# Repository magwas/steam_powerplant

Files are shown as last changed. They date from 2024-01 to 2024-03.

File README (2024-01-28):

An Open Hardware RISC-V based rugged, watercooled laptop with steampunk design.

Design Goals:

- based on the HiFive Unmatched Rev B board, because it is RISC-V
- actually useable
- waterproof
- shock proof
- long battery life
- water cooled
- steampunk

Not Design Goals:

- small
- lightweight

I wanted a RISC-V laptop. 
I usually carry my laptop in my car, and sometimes things happen to it.
So I choose ruggedness over lightness.
The laptop is my single most important object, so I looked up the parts I need, without regard to their price.
Well, later I added up the prices, and got a little shock.
But I have already ordered everything, so...

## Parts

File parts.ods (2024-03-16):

what | type | price (HUF) | dimensions | remark | delivery | url
summary |  | 926262.84
motherboard | hifive unmatched rev b | 273,475 | 170x170x40 | deadend | delivered | https://hu.mouser.com/ProductDetail/SiFive/HF105-001?qs=Imq1NPwxi75JBw6ulD0quQ%3D%3D
monitor+touch | ZSUS 15.6 inch | 40,581 | 345x194x10 |  | delivered | https://www.aliexpress.com/item/1005006082064188.html
kbd | K-TEK-B312-OTB-KP-FN-BL-DWP | 126,000 | 330x123x(33.5+13) | deadend | delivered | https://www.key-tek.cn/Productview.asp?id=1040
ssd | Kingspec XG 7000 | 23,776 |  | 1 TB NVME | https://www.microstore.hu/index.php?route=account/order | https://www.newegg.com/KingSpec-1TB-XG-7000-Series/p/0D9-000D-00171?Item=9SIB1V8JVN3873
wifi | a régi gépből |  |  |  | delivered
accumulators | Sony VTC6 18650 3000 mAh | 140,400 | 18*65 | 4*4 db 14.4V |  | https://www.intercell.hu/sony_vtc6_18650_37v_3000mah_us18650vtc6_li-ion_ipari_cella_akkuakkumulator_30538
BMS | 4S 40A BMS | 34,650 | 63.5x43.18x7.2 |  |  | https://www.amazon.com/Enhanced-Lithium-Protection-Charging-Motorcycle/dp/B08NJTS9DV
mic | CMC-6035T-C1 | 1,865 | 2 pieces |  | https://hu.mouser.com/account/orders/detail | https://hu.mouser.com/ProductDetail/179-CMC-6035T-C1
speaker | ASE05008MS-LWC60 | 8550 | 4 pieces |  | https://hu.mouser.com/account/orders/detail | https://hu.mouser.com/ProductDetail/665-ASE05008MS-LWC60
camera | arducam | 12,200 | 38x38 | deadend | delivered | https://www.amazon.com/Arducam-Computer-Automatic-Switching-All-Day/dp/B0829HZ3Q7?rnid=59788738011&s=pc
camera | SEN0286 | 18,135 | two pieces |  | https://hu.mouser.com/account/orders/detail?qs=9C%2fvjDbyW3XbZVweW%2fGf%2f3c3bGPWTQrU4GrpttTNG8U%3d | https://hu.mouser.com/ProductDetail/426-SEN0286
pump |  |  |  |  |  | https://www.newegg.com/p/37B-0003-00087?Item=9SIAEKSAUY1026
box | sárgaréz lemez 0.7 | 48,768 | 1x300x2000 |  | delivered | https://vasaruhaz.hu/sargarez-vorosrez-bronz/sargarez-lemezek/sargarez-lemez-cu-zn-37-fk0710002000-2209
pcie riser 90 degrees |  | 3500 | 116x41x13 |  | delivered | https://www.amazon.com/GODSHARK-PCI-Express-Riser-Degree-Adapter/dp/B07VV18PQD
video card | amd radeon R7 240 | 10385 | 146x70x2.5 |  | delivered | https://www.amazon.com/PowerColor-Radeon-240-64-bit-Graphics/dp/B09YHVRYNH?rnid=386442011&s=pc
Usb 3.0 hub |  | 3000 |  |  |  | https://www.amazon.com/Extender-Splitter-MacBook-Chromebook-Pixelbook/dp/B09MLRPTT2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
battery springs | 1,5x10/18x13, 1+3+1 | 10100 |  | 1.5*5 mm laposan |  | https://rugobolt.hu/Kupos-nyomorugo-15x10/18x13-mm-menetszam-1-3-1-nat
copper braid | 9.5x7.6m | 10251 |  | 7.6m |  | https://www.techflex.de/flexo-copper-copper-braid-for-grounding-and-shielding.html
silicone tube | 7x10 szilikon cső | 2655 | Din=7 Dout=10 | 5m | delivered | https://szilikon-webaruhaz.hu/id/00024-7x10-mm-es-szilikon-cso
copper tube cső | 20x1x4000 | 16720 |  | 4m | no | https://vasaruhaz.hu/sargarez-vorosrez-bronz/sargarez-cso/sargarez-cso-cuzn-37-fk2014000-2274
filter coil | Rtoroid=2 N=77 Rcoil=0.5 Dwire=2 | 0 | D=10 réz rúdból a tórusz | 4.7 uH |  | http://hyperphysics.phy-astr.gsu.edu/hbase/magnetic/indtor.html
bronze rod | D=10 |  |  |  | no
LM2576T-12 | 4db | 8452 | 5-TO220 | deadend | delivered | https://hu.mouser.com/ProductDetail/926-LM2596T-12-LF03
capacitor | 1000 uF 50V 4db | 279.8 | 12.5x20 | deadend | delivered
capacitor | 100uF 4db | 91.28 | 8x12 | deadend | delivered
diode | 1N5822 4db | 158.76 | 5.6x9.5 | deadend | delivered
fuse | BD280-1130-20/16 |  |  |  | delivered | https://hu.mouser.com/ProductDetail/Littelfuse/BD280-1130-20-16?qs=bZ3KlHYEm0Y61%252BMNFrrJgA%3D%3D
copper wire | 1 punds, 12 awg d=12mm | 17521 |  |  | delivered | https://www.amazon.com/Electric-Copper-Enameled-Industrial-Transmission/dp/B0BN6Y6PN4
usb connector | musb-A511-N1 * 4 |  |  |  | delivered | https://hu.mouser.com/datasheet/2/18/1/AMPH_S_A0003149851_1-2536612.pdf
rj45 | mrjr5c80M1 |  |  |  | delivered | https://cdn.amphenol-cs.com/media/wysiwyg/files/drawing/p-mrjr-5cxx-xc.pdf
on/off switch |  |  |  | deadend | delivered | https://hu.mouser.com/ProductDetail/Carling-Technologies/V8BAAV0B-A9C00-000?qs=W0yvOO0ixfG9jnUCBtfRnQ%3D%3D
on/off switch | TMS3T5B2M6RE | 9945 | 5 pieces |  | https://hu.mouser.com/account/orders/detail?qs=9C%2fvjDbyW3XbZVweW%2fGf%2f3c3bGPWTQrU4GrpttTNG8U%3d | https://hu.mouser.com/ProductDetail/506-TMS3T5B2M6RE
glass plate for my 3d printer |  | 6800 |  |  | https://www.szamlazz.hu/szamla/fiok/wc2u6sn7r4264vhrz755tqzbhm9tj23dq7re?szfejguid=f8qyks3z6pzmtfh7te5a56ia
alu plate |  | 17100 | 1x1000x2000 |  | delivered
wood | zebrano | 11000 |  |  | delivered
ATX from 12V | picopsu | 34000 |  |  |  | https://mitxpc.com/products/pspsu150ac120
M4x5 screw | 200 pieces | 5411 |  |  | https://www.mcmaster.com/order-history/order/65d309e477a2e629e022db77/ | https://www.mcmaster.com/catalog/130/3478/97595A276
M4 nut | 200 pieces | 3608 |  |  | https://www.mcmaster.com/order-history/order/65d309e477a2e629e022db77/ | https://www.mcmaster.com/catalog/130/3635/90690A030
pointing stick |  | 26885 |  | ordered |  | https://www.sprintek.com/en/products/pointing_stick/SK8707-06.aspx

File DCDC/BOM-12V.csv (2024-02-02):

Part | Manufacturer | Part Number | Quantity | Price ($) | Footprint (mm²) | Description
Ccomp3-3 | MuRata | GRM1555C1H911JA01D | 1 | 0.02 | 3 | Cap: 910 pF Total Derated Cap: 910 pF VDC: 50 V ESR: 1 mΩ Package: 0402
Cilim-3 | MuRata | GRM1885C2A100JA01D | 1 | 0.02 | 4.68 | Cap: 10 pF Total Derated Cap: 10 pF VDC: 100 V ESR: 1 mΩ Package: 0603
Css-3 | MuRata | GRM155R71C563KA88D | 1 | 0.01 | 3 | Cap: 56 nF Total Derated Cap: 56 nF VDC: 16 V ESR: 1 mΩ Package: 0402
Cin-3 | MuRata | GRM32ER71H475KA88L | 1 | 0.16 | 14.7 | Cap: 4.7 µF Total Derated Cap: 3.3 µF VDC: 50 V ESR: 1 mΩ Package: 1210
Ruv1-3 | Yageo | RC0201FR-7D68K1L | 1 | 0.01 | 2.08 | Resistance: 68.1 kΩ Tolerance: 1.0% Power: 50 mW
Ccomp2-3 | MuRata | GRM155R71H122KA01D | 1 | 0.01 | 3 | Cap: 1.2 nF Total Derated Cap: 1.2 nF VDC: 50 V ESR: 1 mΩ Package: 0402
Ccomp1-3 | MuRata | GRM155R71C153KA01D | 1 | 0.01 | 3 | Cap: 15 nF Total Derated Cap: 15 nF VDC: 16 V ESR: 1 mΩ Package: 0402
Rt-3 | Vishay-Dale | CRCW040269K8FKED | 1 | 0.01 | 3 | Resistance: 69.8 kΩ Tolerance: 1.0% Power: 63 mW
M1-3 | Texas Instruments | CSD17581Q3A | 1 | 0.18 | 18.49 | VdsMax: 30 V IdsMax: 60 Amps
Rfbb-3 | Vishay-Dale | CRCW04021K27FKED | 1 | 0.01 | 3 | Resistance: 1.27 kΩ Tolerance: 1.0% Power: 63 mW
Rcomp2-3 | Vishay-Dale | CRCW04021K82FKED | 1 | 0.01 | 3 | Resistance: 1.82 kΩ Tolerance: 1.0% Power: 63 mW
Cbst-3 | MuRata | GRM188R61E104KA01D | 1 | 0.01 | 4.68 | Cap: 100 nF Total Derated Cap: 67 nF VDC: 25 V ESR: 30 mΩ Package: 0603
Rfbt-3 | Yageo | RC0603FR-0718KL | 1 | 0.01 | 4.68 | Resistance: 18 kΩ Tolerance: 1.0% Power: 100 mW
Rvin-3 | Vishay-Dale | CRCW06032R10FKEA | 1 | 0.01 | 4.68 | Resistance: 2.1 Ω Tolerance: 1.0% Power: 100 mW
Cvin-3 | TDK | CGA3E2X7R1H104K080AA | 1 | 0.01 | 4.68 | Cap: 100 nF Total Derated Cap: 82 nF VDC: 50 V ESR: 29.6 mΩ Package: 0603
Rpgood-3 | Yageo | RC0603FR-0720KL | 1 | 0.01 | 4.68 | Resistance: 20 kΩ Tolerance: 1.0% Power: 100 mW
U1-3 | Texas Instruments | LM5145RGYR | 1 | 1.318 | 24.75
Cvcc-3 | TDK | C1005X5R1V225K050BC | 1 | 0.06 | 3 | Cap: 2.2 µF Total Derated Cap: 93 nF VDC: 35 V ESR: 1 mΩ Package: 0402
M2-3 | Texas Instruments | CSD17577Q3A | 1 | 0.15 | 18.49 | VdsMax: 30 V IdsMax: 35 Amps
L1-3 | Coilcraft | XAL1010-472MEB | 1 | 1.71 | 159.6 | L: 4.7 µH DCR: 5.2 mΩ IDC: 24 A
Cout-3 | Panasonic | 20SVPF56MX | 1 | 0.47 | 53.29 | Cap: 56 µF Total Derated Cap: 56 µF VDC: 20 V ESR: 30 mΩ Package: 5x5.9
Ruv2-3 | Yageo | RC0603FR-079K1L | 1 | 0.01 | 4.68 | Resistance: 9.1 kΩ Tolerance: 1.0% Power: 100 mW
Rilim-3 | Vishay-Dale | CRCW0402619RFKED | 1 | 0.01 | 3 | Resistance: 619 Ω Tolerance: 1.0% Power: 63 mW
Rcomp1-3 | Vishay-Dale | CRCW04021K78FKED | 1 | 0.01 | 3 | Resistance: 1.78 kΩ Tolerance: 1.0% Power: 63 mW
Rvcc-3 | Yageo | RC0603FR-0720KL | 1 | 0.01 | 4.68 | Resistance: 20 kΩ Tolerance: 1.0% Power: 100 mW

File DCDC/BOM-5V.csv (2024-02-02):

Part | Manufacturer | Part Number | Quantity | Price ($) | Footprint (mm²) | Description
Ccomp3-1 | TDK | CGA2B2X7R1H471K050BA | 1 | 0.01 | 3 | Cap: 470 pF Total Derated Cap: 470 pF VDC: 50 V ESR: 4.96 Ω Package: 0402
Cilim-1 | MuRata | GQM2195C2A5R1CB01D | 1 | 0.15 | 6.75 | Cap: 5.1 pF Total Derated Cap: 5.1 pF VDC: 100 V ESR: 1 mΩ Package: 0805
Css-1 | MuRata | GRM155R71C563KA88D | 1 | 0.01 | 3 | Cap: 56 nF Total Derated Cap: 56 nF VDC: 16 V ESR: 1 mΩ Package: 0402
Cin-1 | MuRata | GRM32ER71H475KA88L | 1 | 0.16 | 14.7 | Cap: 4.7 µF Total Derated Cap: 3.3 µF VDC: 50 V ESR: 1 mΩ Package: 1210
Ruv1-1 | Yageo | RC0201FR-7D68K1L | 1 | 0.01 | 2.08 | Resistance: 68.1 kΩ Tolerance: 1.0% Power: 50 mW
Ccomp2-1 | MuRata | GRM155R71H821KA01D | 1 | 0.01 | 3 | Cap: 820 pF Total Derated Cap: 820 pF VDC: 50 V ESR: 1 mΩ Package: 0402
Ccomp1-1 | MuRata | GRM155R71C822KA01D | 1 | 0.01 | 3 | Cap: 8.2 nF Total Derated Cap: 8.2 nF VDC: 16 V ESR: 1 mΩ Package: 0402
Rt-1 | Vishay-Dale | CRCW040239K2FKED | 1 | 0.01 | 3 | Resistance: 39.2 kΩ Tolerance: 1.0% Power: 63 mW
M1-1 | Texas Instruments | CSD17579Q3A | 1 | 0.12 | 18.49 | VdsMax: 30 V IdsMax: 20 Amps
Rfbb-1 | Vishay-Dale | CRCW04023K40FKED | 1 | 0.01 | 3 | Resistance: 3.4 kΩ Tolerance: 1.0% Power: 63 mW
Rcomp2-1 | Vishay-Dale | CRCW0402162RFKED | 1 | 0.01 | 3 | Resistance: 162 Ω Tolerance: 1.0% Power: 63 mW
Cbst-1 | MuRata | GRM188R61E104KA01D | 1 | 0.01 | 4.68 | Cap: 100 nF Total Derated Cap: 67 nF VDC: 25 V ESR: 30 mΩ Package: 0603
Rfbt-1 | Yageo | RC0603FR-0718KL | 1 | 0.01 | 4.68 | Resistance: 18 kΩ Tolerance: 1.0% Power: 100 mW
Rvin-1 | Vishay-Dale | CRCW06032R10FKEA | 1 | 0.01 | 4.68 | Resistance: 2.1 Ω Tolerance: 1.0% Power: 100 mW
Cvin-1 | TDK | CGA3E2X7R1H104K080AA | 1 | 0.01 | 4.68 | Cap: 100 nF Total Derated Cap: 82 nF VDC: 50 V ESR: 29.6 mΩ Package: 0603
Rpgood-1 | Yageo | RC0603FR-0720KL | 1 | 0.01 | 4.68 | Resistance: 20 kΩ Tolerance: 1.0% Power: 100 mW
U1-1 | Texas Instruments | LM5145RGYR | 1 | 1.318 | 24.75
Cvcc-1 | TDK | C1005X5R1V225K050BC | 1 | 0.06 | 3 | Cap: 2.2 µF Total Derated Cap: 93 nF VDC: 35 V ESR: 1 mΩ Package: 0402
M2-1 | Texas Instruments | CSD17577Q3A | 1 | 0.15 | 18.49 | VdsMax: 30 V IdsMax: 35 Amps
L1-1 | Coilcraft | XAL1010-332MEB | 1 | 1.71 | 159.6 | L: 3.3 µH DCR: 3.7 mΩ IDC: 25 A
Cout-1 | Kemet | C1210C106K8PACTU | 2 | 0.22 | 14.7 | Cap: 10 µF Total Derated Cap: 19 µF VDC: 10 V ESR: 8 mΩ Package: 1210
Ruv2-1 | Yageo | RC0603FR-079K1L | 1 | 0.01 | 4.68 | Resistance: 9.1 kΩ Tolerance: 1.0% Power: 100 mW
Rilim-1 | Vishay-Dale | CRCW04021K74FKED | 1 | 0.01 | 3 | Resistance: 1.74 kΩ Tolerance: 1.0% Power: 63 mW
Rcomp1-1 | Vishay-Dale | CRCW04021K54FKED | 1 | 0.01 | 3 | Resistance: 1.54 kΩ Tolerance: 1.0% Power: 63 mW
Rvcc-1 | Yageo | RC0603FR-0720KL | 1 | 0.01 | 4.68 | Resistance: 20 kΩ Tolerance: 1.0% Power: 100 mW

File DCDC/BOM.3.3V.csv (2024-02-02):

Part | Manufacturer | Part Number | Quantity | Price ($) | Footprint (mm²) | Description
Ccomp3-2 | TDK | CGA2B2X7R1H331K050BA | 1 | 0.01 | 3 | Cap: 330 pF Total Derated Cap: 330 pF VDC: 50 V ESR: 6.53 Ω Package: 0402
Cilim-2 | MuRata | GQM2195C2A5R1CB01D | 1 | 0.15 | 6.75 | Cap: 5.1 pF Total Derated Cap: 5.1 pF VDC: 100 V ESR: 1 mΩ Package: 0805
Css-2 | MuRata | GRM155R71C563KA88D | 1 | 0.01 | 3 | Cap: 56 nF Total Derated Cap: 56 nF VDC: 16 V ESR: 1 mΩ Package: 0402
Cin-2 | MuRata | GRM32ER71H475KA88L | 1 | 0.16 | 14.7 | Cap: 4.7 µF Total Derated Cap: 3.3 µF VDC: 50 V ESR: 1 mΩ Package: 1210
Ruv1-2 | Yageo | RC0201FR-7D68K1L | 1 | 0.01 | 2.08 | Resistance: 68.1 kΩ Tolerance: 1.0% Power: 50 mW
Ccomp2-2 | MuRata | GRM155R71C102KA01D | 1 | 0.01 | 3 | Cap: 1 nF Total Derated Cap: 1 nF VDC: 16 V ESR: 1 mΩ Package: 0402
Ccomp1-2 | MuRata | GRM155R71C822KA01D | 1 | 0.01 | 3 | Cap: 8.2 nF Total Derated Cap: 8.2 nF VDC: 16 V ESR: 1 mΩ Package: 0402
Rt-2 | Vishay-Dale | CRCW040239K2FKED | 1 | 0.01 | 3 | Resistance: 39.2 kΩ Tolerance: 1.0% Power: 63 mW
M1-2 | Texas Instruments | CSD17579Q3A | 1 | 0.12 | 18.49 | VdsMax: 30 V IdsMax: 20 Amps
Rfbb-2 | Vishay-Dale | CRCW04025K76FKED | 1 | 0.01 | 3 | Resistance: 5.76 kΩ Tolerance: 1.0% Power: 63 mW
Rcomp2-2 | Vishay-Dale | CRCW0402237RFKED | 1 | 0.01 | 3 | Resistance: 237 Ω Tolerance: 1.0% Power: 63 mW
Cbst-2 | MuRata | GRM188R61E104KA01D | 1 | 0.01 | 4.68 | Cap: 100 nF Total Derated Cap: 67 nF VDC: 25 V ESR: 30 mΩ Package: 0603
Rfbt-2 | Yageo | RC0603FR-0718KL | 1 | 0.01 | 4.68 | Resistance: 18 kΩ Tolerance: 1.0% Power: 100 mW
Rvin-2 | Vishay-Dale | CRCW06032R10FKEA | 1 | 0.01 | 4.68 | Resistance: 2.1 Ω Tolerance: 1.0% Power: 100 mW
Cvin-2 | TDK | CGA3E2X7R1H104K080AA | 1 | 0.01 | 4.68 | Cap: 100 nF Total Derated Cap: 82 nF VDC: 50 V ESR: 29.6 mΩ Package: 0603
Rpgood-2 | Yageo | RC0603FR-0720KL | 1 | 0.01 | 4.68 | Resistance: 20 kΩ Tolerance: 1.0% Power: 100 mW
U1-2 | Texas Instruments | LM5145RGYR | 1 | 1.318 | 24.75
Cvcc-2 | TDK | C1005X5R1V225K050BC | 1 | 0.06 | 3 | Cap: 2.2 µF Total Derated Cap: 93 nF VDC: 35 V ESR: 1 mΩ Package: 0402
M2-2 | Texas Instruments | CSD17577Q3A | 1 | 0.15 | 18.49 | VdsMax: 30 V IdsMax: 35 Amps
L1-2 | Bourns | SRP1270-2R2M | 1 | 0.83 | 246.49 | L: 2.2 µH DCR: 4.2 mΩ IDC: 22 A
Cout-2 | Kemet | C1210C106K8PACTU | 2 | 0.22 | 14.7 | Cap: 10 µF Total Derated Cap: 20 µF VDC: 10 V ESR: 8 mΩ Package: 1210
Ruv2-2 | Yageo | RC0603FR-079K1L | 1 | 0.01 | 4.68 | Resistance: 9.1 kΩ Tolerance: 1.0% Power: 100 mW
Rilim-2 | Vishay-Dale | CRCW04021K50FKED | 1 | 0.01 | 3 | Resistance: 1.5 kΩ Tolerance: 1.0% Power: 63 mW
Rcomp1-2 | Vishay-Dale | CRCW04021K27FKED | 1 | 0.01 | 3 | Resistance: 1.27 kΩ Tolerance: 1.0% Power: 63 mW
Rvcc-2 | Yageo | RC0603FR-0720KL | 1 | 0.01 | 4.68 | Resistance: 20 kΩ Tolerance: 1.0% Power: 100 mW

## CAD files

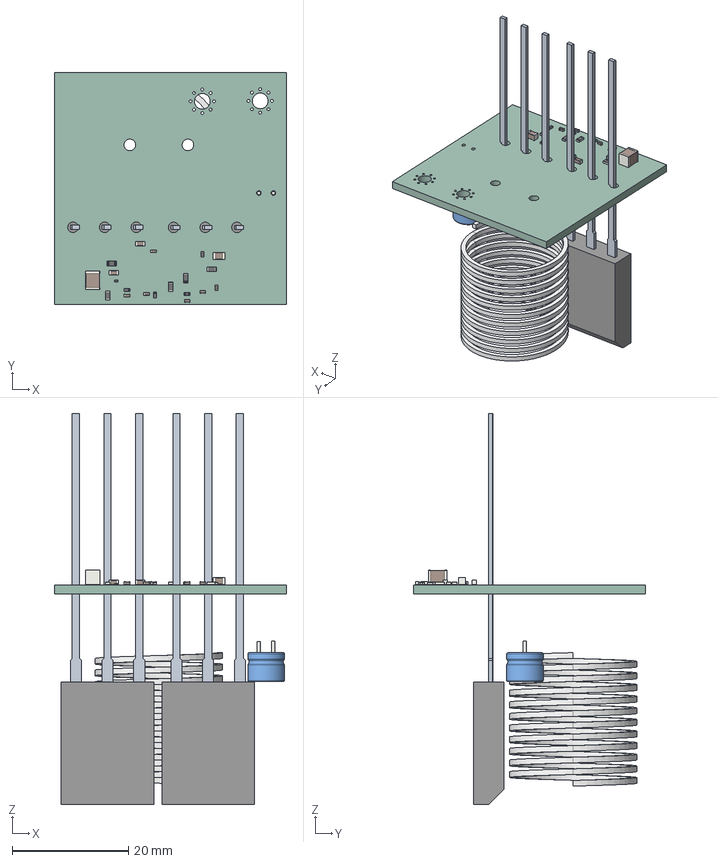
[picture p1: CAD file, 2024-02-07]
DCDC/dcdc3.step
40.0 x 40.0 x 67.3 mm
C_0805_2012Metric
R_0402_1005Metric x 5
R_0603_1608Metric x 5
C_0402_1005Metric x 5
C_1210_3225Metric
C_0603_1608Metric x 2
R_0201_0603Metric
C_Radial_D63mm_H50mm_P250mm
ASSEMBLY x 2
_autosave-dcdc3_PCB

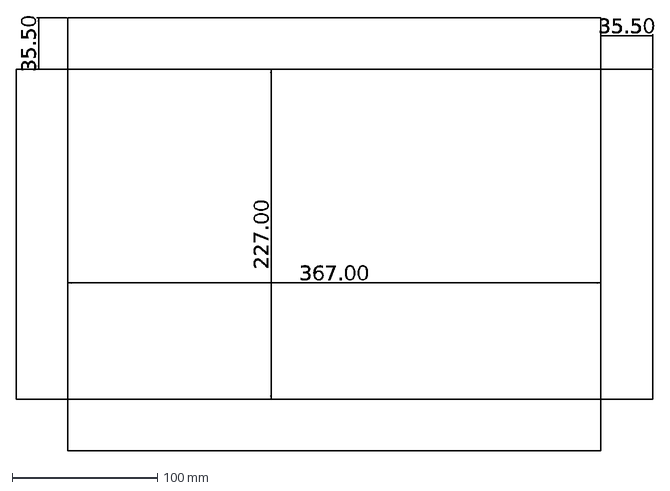
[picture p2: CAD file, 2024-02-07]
plans/bottom_box_origami.dxf
35.50
367.00
227.00

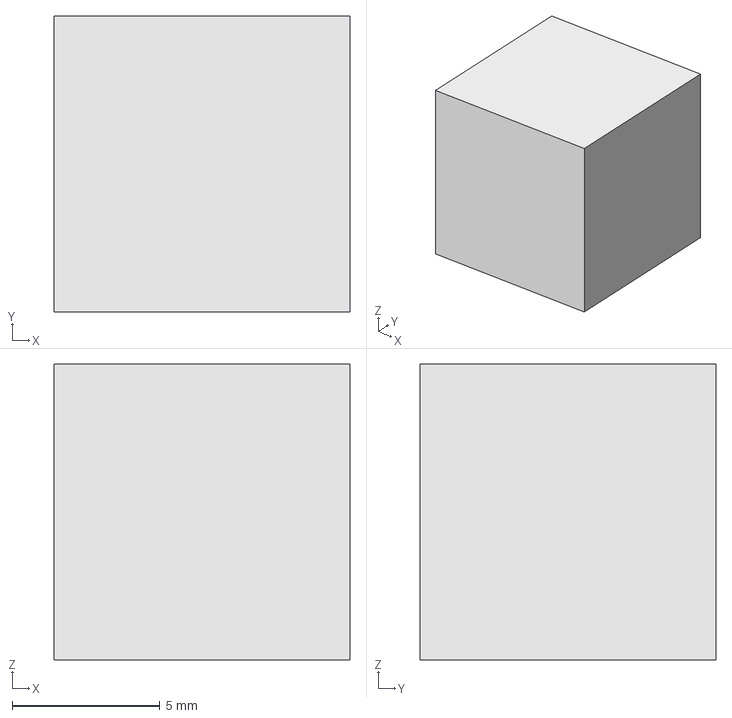
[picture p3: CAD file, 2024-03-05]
pump.FCStd
10.0 x 10.0 x 10.0 mm

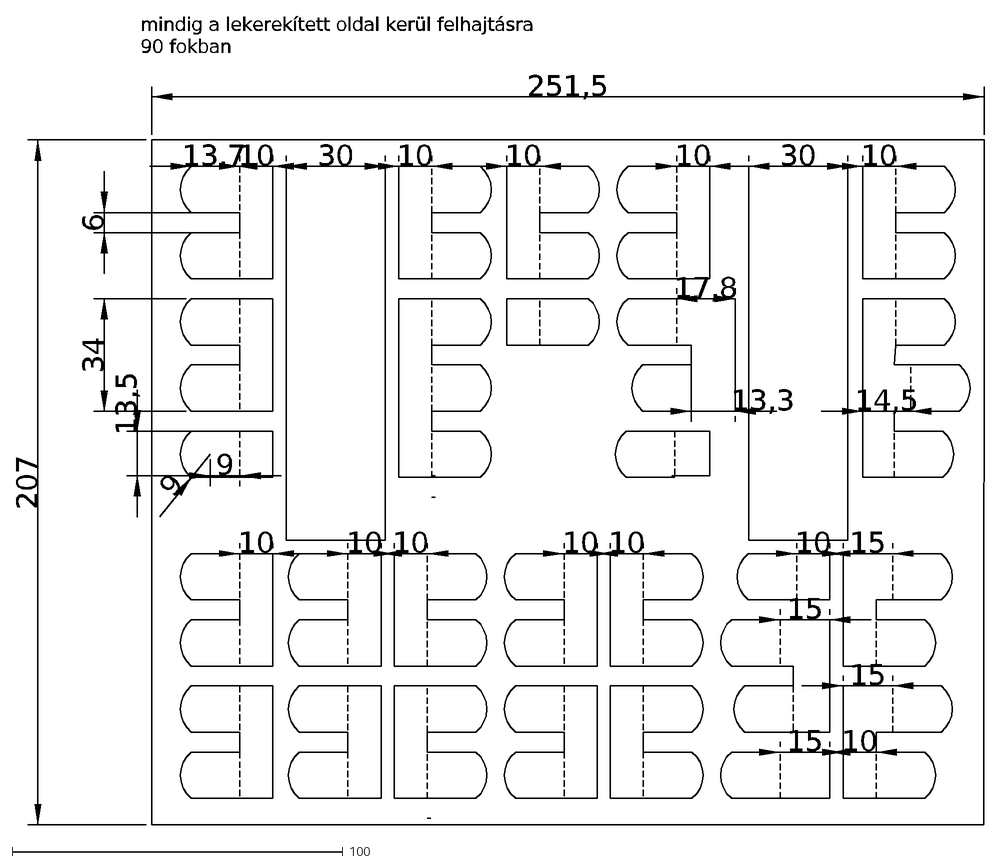
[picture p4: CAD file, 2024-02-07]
battery_contacts.dxf
9
10
13,7
13,5
17,8
13,3
30
14,5
6
15
34
207
251,5
mindig a lekerekített oldal kerül felhajtásra 90 fokban

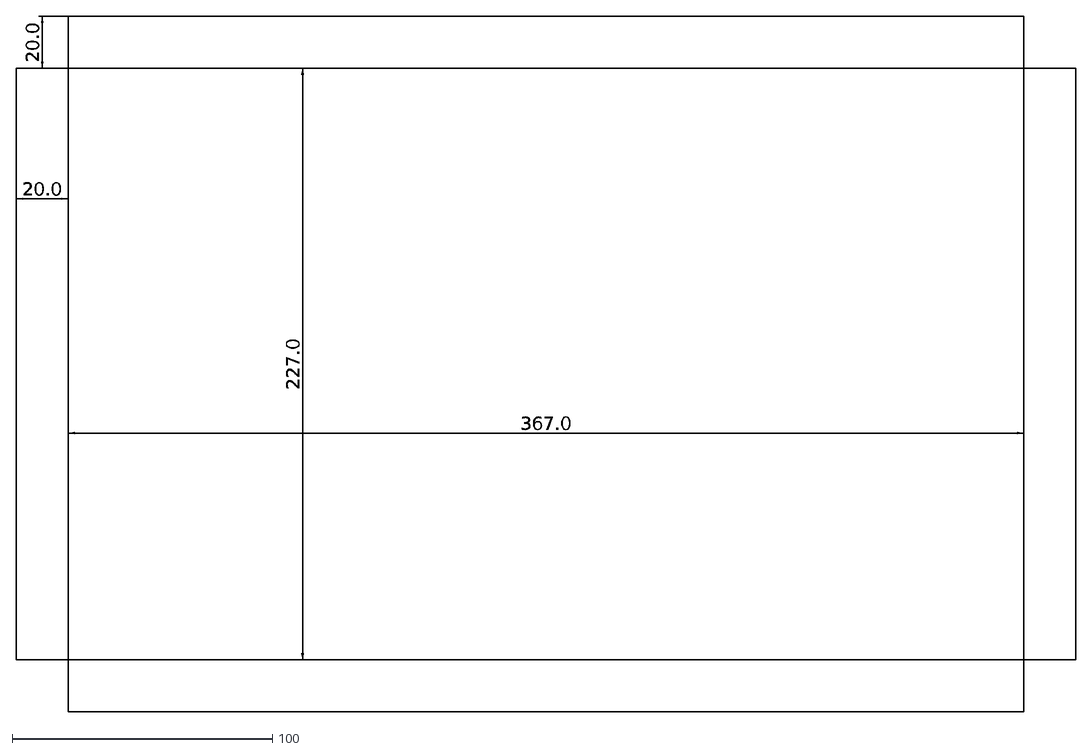
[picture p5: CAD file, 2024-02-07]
plans/top_box_origami.dxf
227.0
20.0
367.0

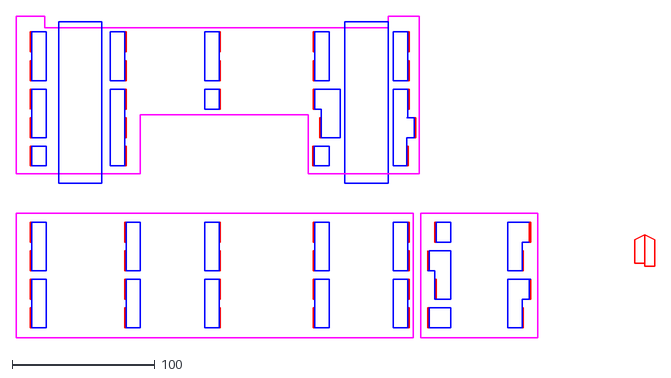
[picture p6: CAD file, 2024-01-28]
sketches.dxf
447.0 x 225.0

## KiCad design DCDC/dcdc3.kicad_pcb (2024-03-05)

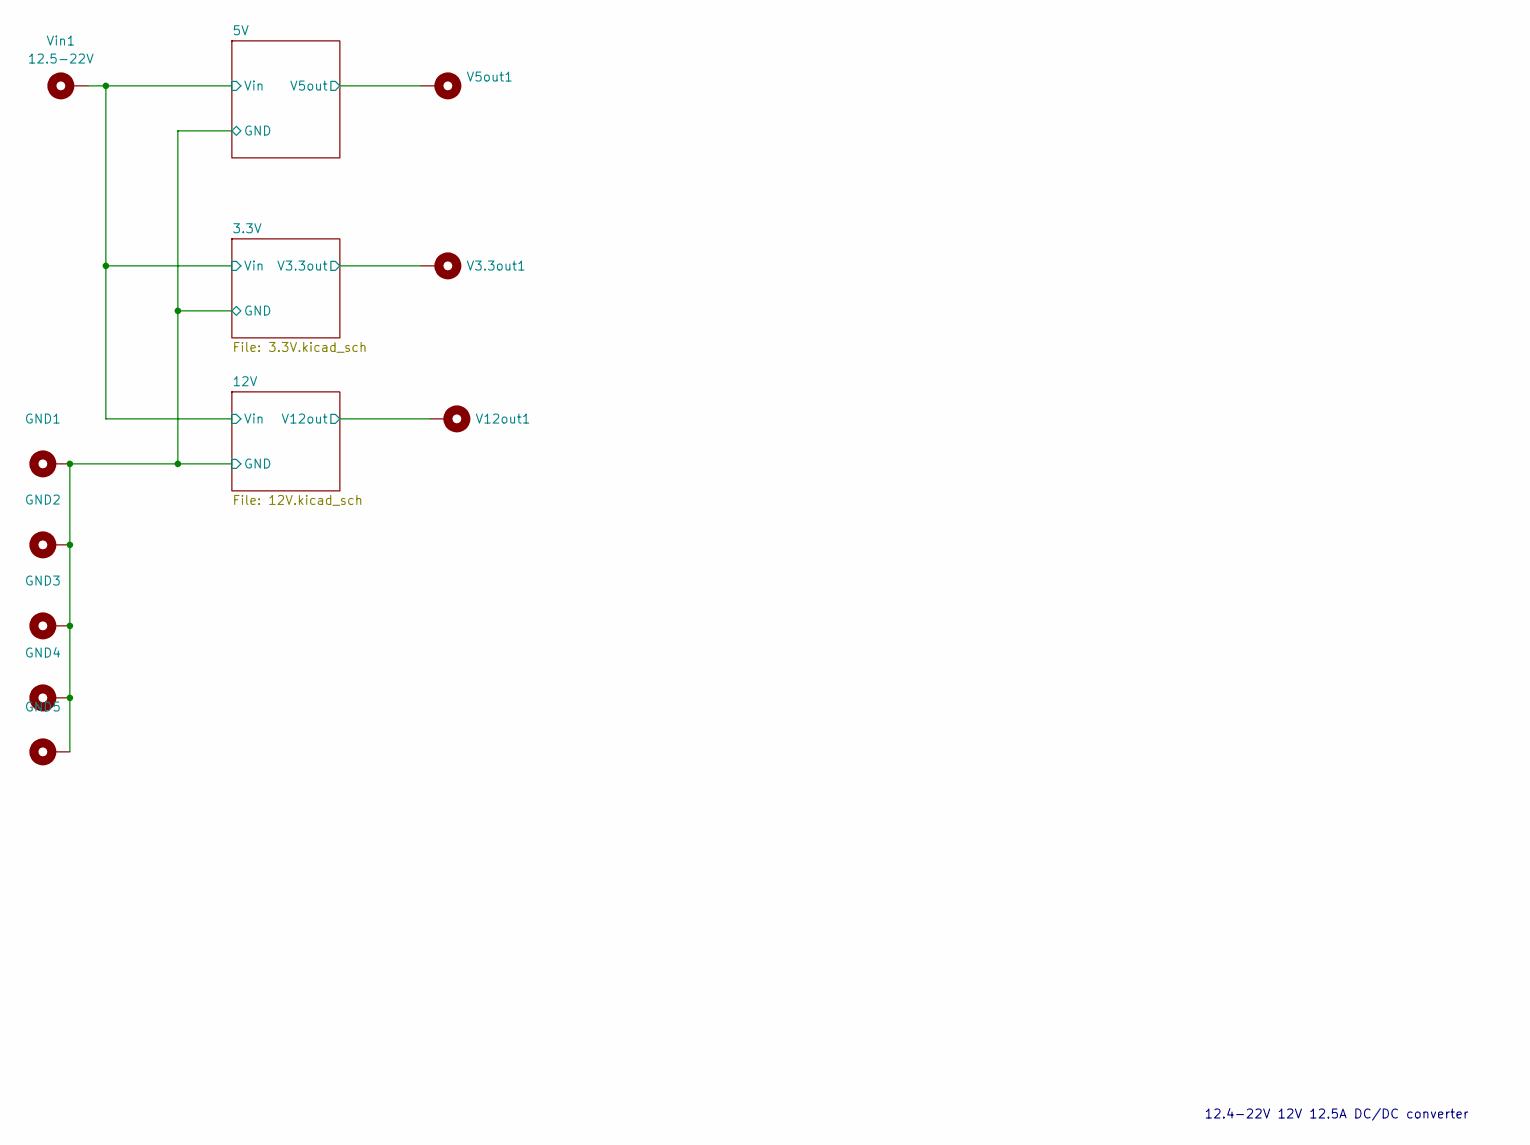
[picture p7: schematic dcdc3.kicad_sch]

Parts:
GND1, GND2, GND3, GND4, GND5: MountingHole_2.7mm_M2.5_Pad_Via
V3.3out1, V5out1, V12out1: MountingHole_2.7mm_M2.5_Pad_Via
Vin1: 12.5-22V; MountingHole_2.7mm_M2.5_Pad_Via

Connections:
/3.3V/V3.3out: V3.3out1.1; also elsewhere on the board
/5V/V5out: V5out1.1; also elsewhere on the board
/12V/GND: GND1.1, GND2.1, GND3.1, GND4.1, GND5.1; also elsewhere on the board
/12V/V12out: V12out1.1; also elsewhere on the board
/12V/Vin: Vin1.1; also elsewhere on the board

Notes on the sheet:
12.4-22V 12V 12.5A DC/DC converter

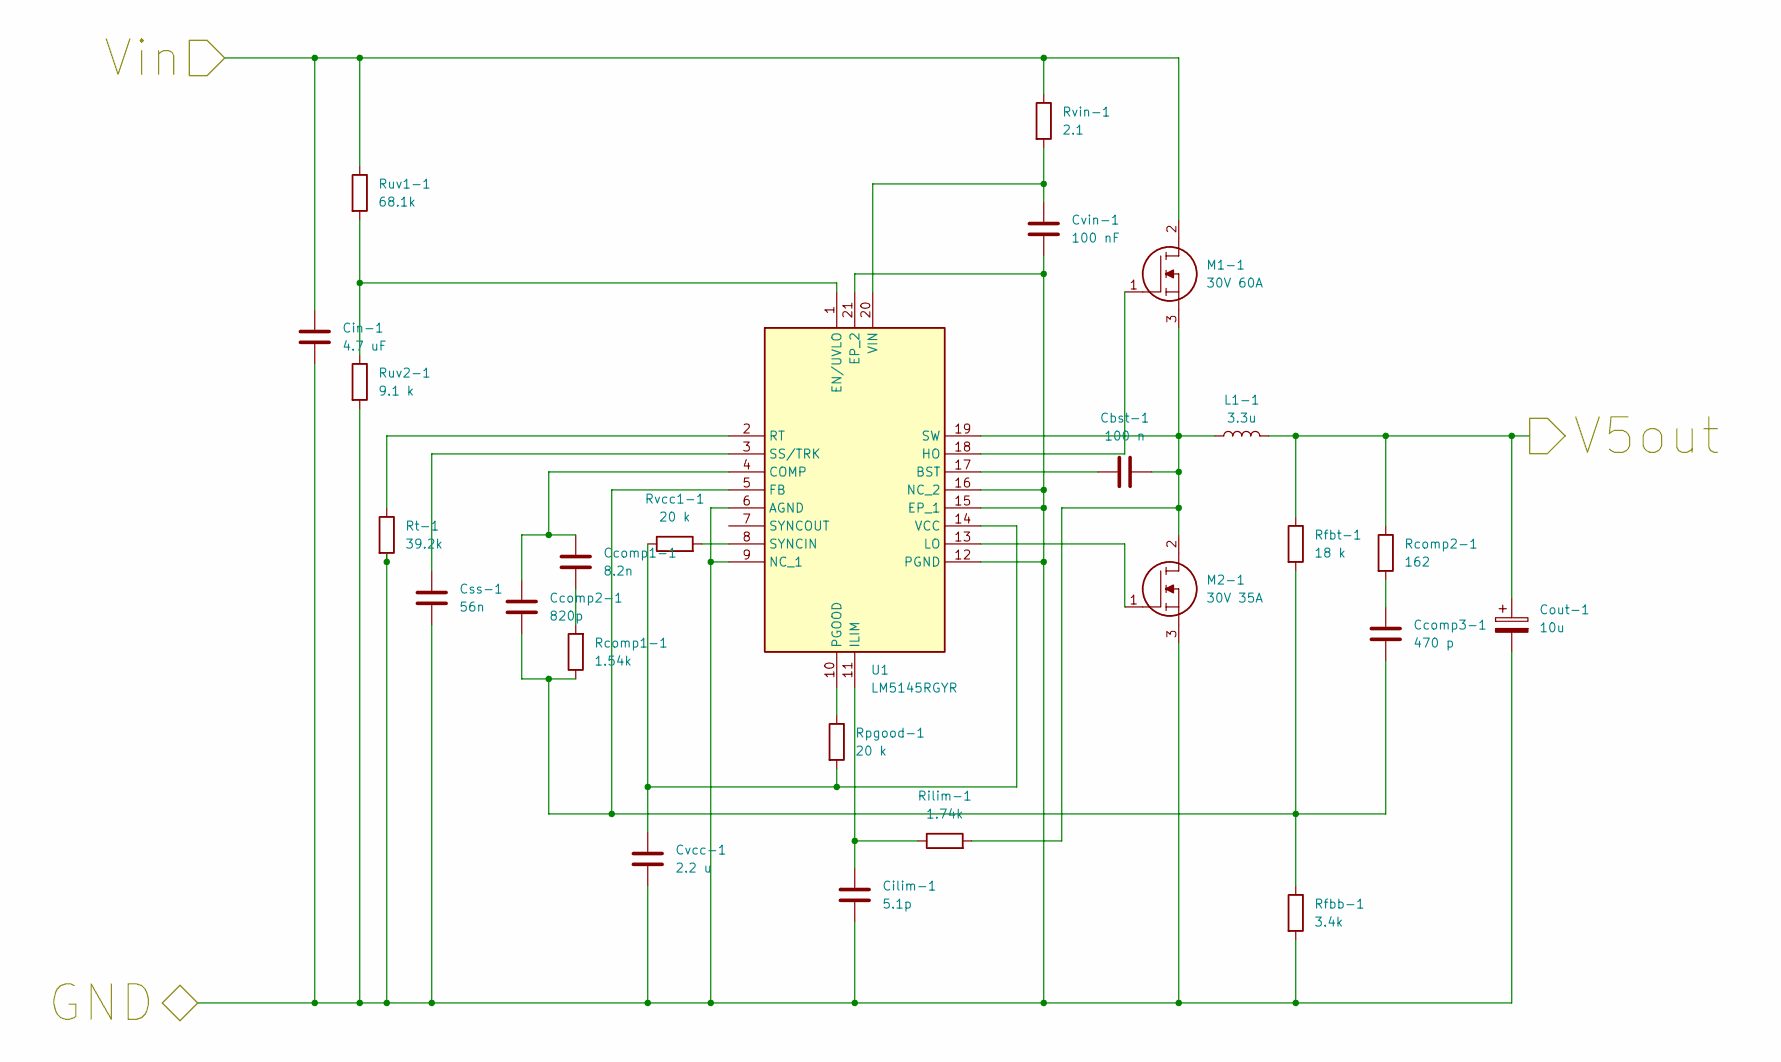
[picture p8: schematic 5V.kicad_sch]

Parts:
Cbst-1: 100 n; C_0603_1608Metric; Manufacturer_Part_Number C0603C104J1RACAUTO
Ccomp1-1: 8.2n; C_0402_1005Metric; Manufacturer_Part_Number GRM155R71C822KA01D
Ccomp2-1: 820p; C_0402_1005Metric; Manufacturer_Part_Number GRM155R71H821KA01D
Ccomp3-1: 470 p; C_0402_1005Metric; Manufacturer_Part_Number CGA2B2X7R1H471K050BA
Cilim-1: 5.1p; C_0805_2012Metric; Manufacturer_Part_Number C0805C519DBGACTU
Cin-1: 4.7 uF; C_1210_3225Metric; Manufacturer_Part_Number GRM32ER71H475KA88L
Cout-1: 10u; C_Radial_D10.0mm_H12.5mm_P5.00mm; Manufacturer_Part_Number KTD500B106M55A0T00
Css-1: 56n; C_0402_1005Metric; Manufacturer_Part_Number GRM155R71C563KA88D
Cvcc-1: 2.2 u; C_0402_1005Metric; Manufacturer_Part_Number C1005X5R1V225K050BC
Cvin-1: 100 nF; C_0603_1608Metric; Manufacturer_Part_Number CGA3E2X7R1H104K080AA
L1-1: 3.3u; A3mmCoil; Manufacturer_Part_Number D=15mm,N=15,L=15mm,d=2mm
M1-1: 30V 60A; TO545P521X1594X2566-3P; Mouser Part Number 747-IXFX360N10T
M2-1: 30V 35A; TO545P521X1594X2566-3P; Mouser Part Number 747-IXFX360N10T
Rcomp1-1: 1.54k; R_0402_1005Metric; Manufacturer_Part_Number CRCW04021K78FKED
Rcomp2-1: 162; R_0402_1005Metric; Manufacturer_Part_Number CRCW0402162RFKED
Rfbb-1: 3.4k; R_0402_1005Metric; Manufacturer_Part_Number CRCW04023K40FKED
Rfbt-1: 18 k; R_0603_1608Metric; Manufacturer_Part_Number RC0603FR-0718KL
Rilim-1: 1.74k; R_0402_1005Metric; Manufacturer_Part_Number CRCW04021K74FKED
Rpgood-1: 20 k; R_0603_1608Metric; Manufacturer_Part_Number RC0603FR-0720KL
Rt-1: 39.2k; R_0402_1005Metric; Manufacturer_Part_Number CRCW040239K2FKED
Ruv1-1: 68.1k; R_0603_1608Metric; Manufacturer_Part_Number ERA-3VEB6812V
Ruv2-1: 9.1 k; R_0603_1608Metric; Manufacturer_Part_Number RC0603FR-079K1L
Rvcc1-1: 20 k; R_0603_1608Metric; Manufacturer_Part_Number RC0603FR-0720KL
Rvin-1: 2.1; R_0603_1608Metric; Manufacturer_Part_Number CRCW06032R10FKEA
U1: LM5145RGYR; RGY0020B; Manufacturer_Part_Number LM5145RGYR; Mouser Part Number 595-LM5145RGYR

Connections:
/5V/V5out: Cout-1.1, L1-1.2, Rcomp2-1.1, Rfbt-1.1; also elsewhere on the board
/12V/GND: Cilim-1.2, Cin-1.2, Cout-1.2, Css-1.2, Cvcc-1.2, Cvin-1.2, M2-1.3, Rfbb-1.2, Rt-1.2, Ruv2-1.2, U1.6 (AGND), U1.9 (NC_1), U1.12 (PGND), U1.15 (EP_1), U1.16 (NC_2), U1.21 (EP_2); also elsewhere on the board
/12V/Vin: Cin-1.1, M1-1.2, Ruv1-1.1, Rvin-1.1; also elsewhere on the board
unnamed: Ccomp1-1.1, Rcomp1-1.2
unnamed: Ccomp3-1.1, Rcomp2-1.2
unnamed: Cbst-1.1, U1.17 (BST)
unnamed: Ccomp1-1.2, Ccomp2-1.2, U1.4 (COMP)
unnamed: Ruv1-1.2, Ruv2-1.1, U1.1 (EN/UVLO)
unnamed: Ccomp2-1.1, Ccomp3-1.2, Rcomp1-1.1, Rfbb-1.1, Rfbt-1.2, U1.5 (FB)
unnamed: M1-1.1, U1.18 (HO)
unnamed: Cilim-1.1, Rilim-1.1, U1.11 (ILIM)
unnamed: M2-1.1, U1.13 (LO)
unnamed: Rpgood-1.1, U1.10 (PGOOD)
unnamed: Rt-1.1, U1.2 (RT)
unnamed: Css-1.1, U1.3 (SS/TRK)
unnamed: Cbst-1.2, L1-1.1, M1-1.3, M2-1.2, Rilim-1.2, U1.19 (SW)
unnamed: Rvcc1-1.2, U1.8 (SYNCIN)
unnamed: Cvcc-1.1, Rpgood-1.2, Rvcc1-1.1, U1.14 (VCC)
unnamed: Cvin-1.1, Rvin-1.2, U1.20 (VIN)

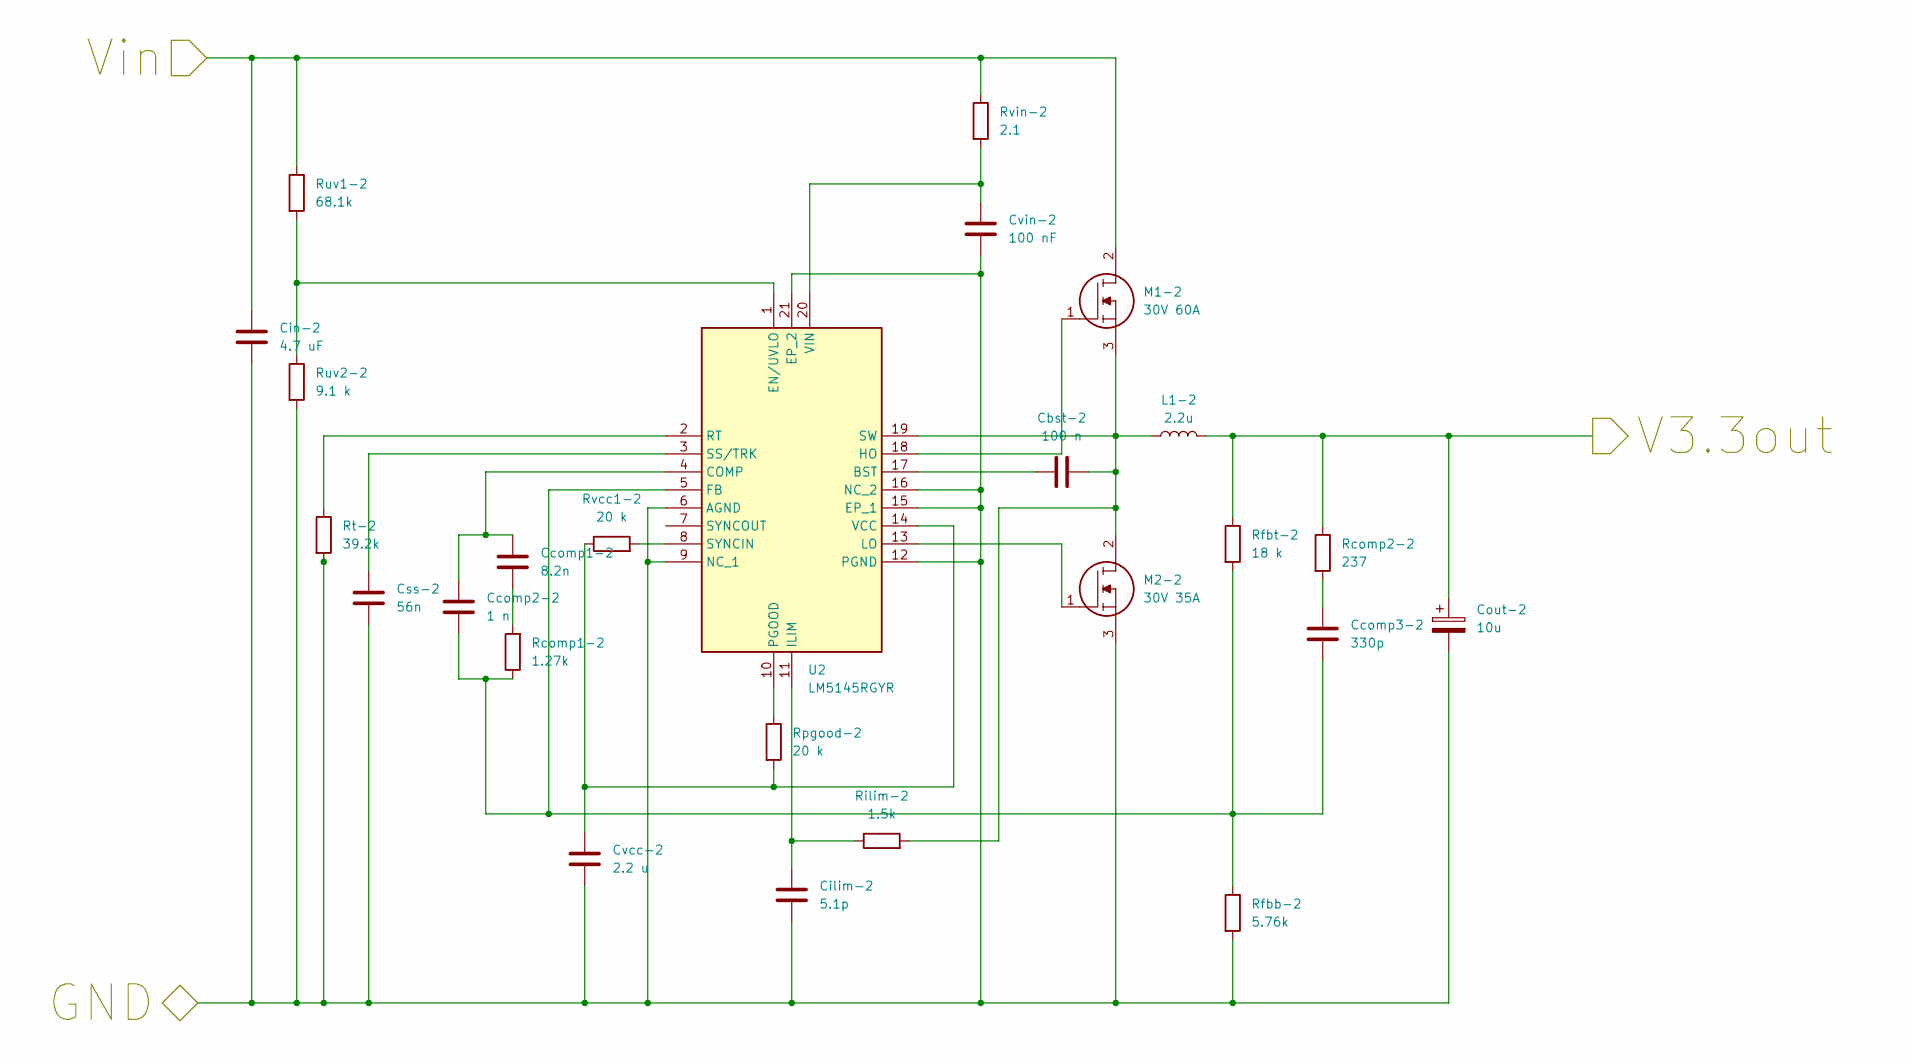
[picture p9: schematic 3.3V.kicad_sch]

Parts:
Cbst-2: 100 n; C_0603_1608Metric; Manufacturer_Part_Number C0603C104J1RACAUTO
Ccomp1-2: 8.2n; C_0402_1005Metric; Manufacturer_Part_Number GRM155R71C822KA01D
Ccomp2-2: 1 n; C_0402_1005Metric; Manufacturer_Part_Number GRM155R71C102KA01D
Ccomp3-2: 330p; C_0402_1005Metric; Manufacturer_Part_Number CGA2B2X7R1H331K050BA
Cilim-2: 5.1p; C_0805_2012Metric; Manufacturer_Part_Number C0805C519DBGACTU
Cin-2: 4.7 uF; C_1210_3225Metric; Manufacturer_Part_Number GRM32ER71H475KA88L
Cout-2: 10u; C_Radial_D10.0mm_H12.5mm_P5.00mm; Manufacturer_Part_Number KTD500B106M55A0T00
Css-2: 56n; C_0402_1005Metric; Manufacturer_Part_Number GRM155R71C563KA88D
Cvcc-2: 2.2 u; C_0402_1005Metric; Manufacturer_Part_Number C1005X5R1V225K050BC
Cvin-2: 100 nF; C_0603_1608Metric; Manufacturer_Part_Number CGA3E2X7R1H104K080AA
L1-2: 2.2u; A3mmCoil; Manufacturer_Part_Number D=15mm,N=10,L=20mm,d=2mm
M1-2: 30V 60A; TO545P521X1594X2566-3P; Mouser Part Number 747-IXFX360N10T
M2-2: 30V 35A; TO545P521X1594X2566-3P; Mouser Part Number 747-IXFX360N10T
Rcomp1-2: 1.27k; R_0402_1005Metric; Manufacturer_Part_Number CRCW04021K27FKED
Rcomp2-2: 237; R_0402_1005Metric; Manufacturer_Part_Number CRCW0402237RFKED
Rfbb-2: 5.76k; R_0402_1005Metric; Manufacturer_Part_Number CRCW04025K76FKED
Rfbt-2: 18 k; R_0603_1608Metric; Manufacturer_Part_Number RC0603FR-0718KL
Rilim-2: 1.5k; R_0402_1005Metric; Manufacturer_Part_Number CRCW04021K50FKED
Rpgood-2: 20 k; R_0603_1608Metric; Manufacturer_Part_Number RC0603FR-0720KL
Rt-2: 39.2k; R_0402_1005Metric; Manufacturer_Part_Number CRCW040239K2FKED
Ruv1-2: 68.1k; R_0603_1608Metric; Manufacturer_Part_Number ERA-3VEB6812V
Ruv2-2: 9.1 k; R_0603_1608Metric; Manufacturer_Part_Number RC0603FR-079K1L
Rvcc1-2: 20 k; R_0603_1608Metric; Manufacturer_Part_Number RC0603FR-0720KL
Rvin-2: 2.1; R_0603_1608Metric; Manufacturer_Part_Number CRCW06032R10FKEA
U2: LM5145RGYR; RGY0020B; Manufacturer_Part_Number LM5145RGYR; Mouser Part Number 595-LM5145RGYR

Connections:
/3.3V/V3.3out: Cout-2.1, L1-2.2, Rcomp2-2.1, Rfbt-2.1; also elsewhere on the board
/12V/GND: Cilim-2.2, Cin-2.2, Cout-2.2, Css-2.2, Cvcc-2.2, Cvin-2.2, M2-2.3, Rfbb-2.2, Rt-2.2, Ruv2-2.2, U2.6 (AGND), U2.9 (NC_1), U2.12 (PGND), U2.15 (EP_1), U2.16 (NC_2), U2.21 (EP_2); also elsewhere on the board
/12V/Vin: Cin-2.1, M1-2.2, Ruv1-2.1, Rvin-2.1; also elsewhere on the board
unnamed: Ccomp1-2.1, Rcomp1-2.2
unnamed: Ccomp3-2.1, Rcomp2-2.2
unnamed: Cbst-2.1, U2.17 (BST)
unnamed: Ccomp1-2.2, Ccomp2-2.2, U2.4 (COMP)
unnamed: Ruv1-2.2, Ruv2-2.1, U2.1 (EN/UVLO)
unnamed: Ccomp2-2.1, Ccomp3-2.2, Rcomp1-2.1, Rfbb-2.1, Rfbt-2.2, U2.5 (FB)
unnamed: M1-2.1, U2.18 (HO)
unnamed: Cilim-2.1, Rilim-2.1, U2.11 (ILIM)
unnamed: M2-2.1, U2.13 (LO)
unnamed: Rpgood-2.1, U2.10 (PGOOD)
unnamed: Rt-2.1, U2.2 (RT)
unnamed: Css-2.1, U2.3 (SS/TRK)
unnamed: Cbst-2.2, L1-2.1, M1-2.3, M2-2.2, Rilim-2.2, U2.19 (SW)
unnamed: Rvcc1-2.2, U2.8 (SYNCIN)
unnamed: Cvcc-2.1, Rpgood-2.2, Rvcc1-2.1, U2.14 (VCC)
unnamed: Cvin-2.1, Rvin-2.2, U2.20 (VIN)

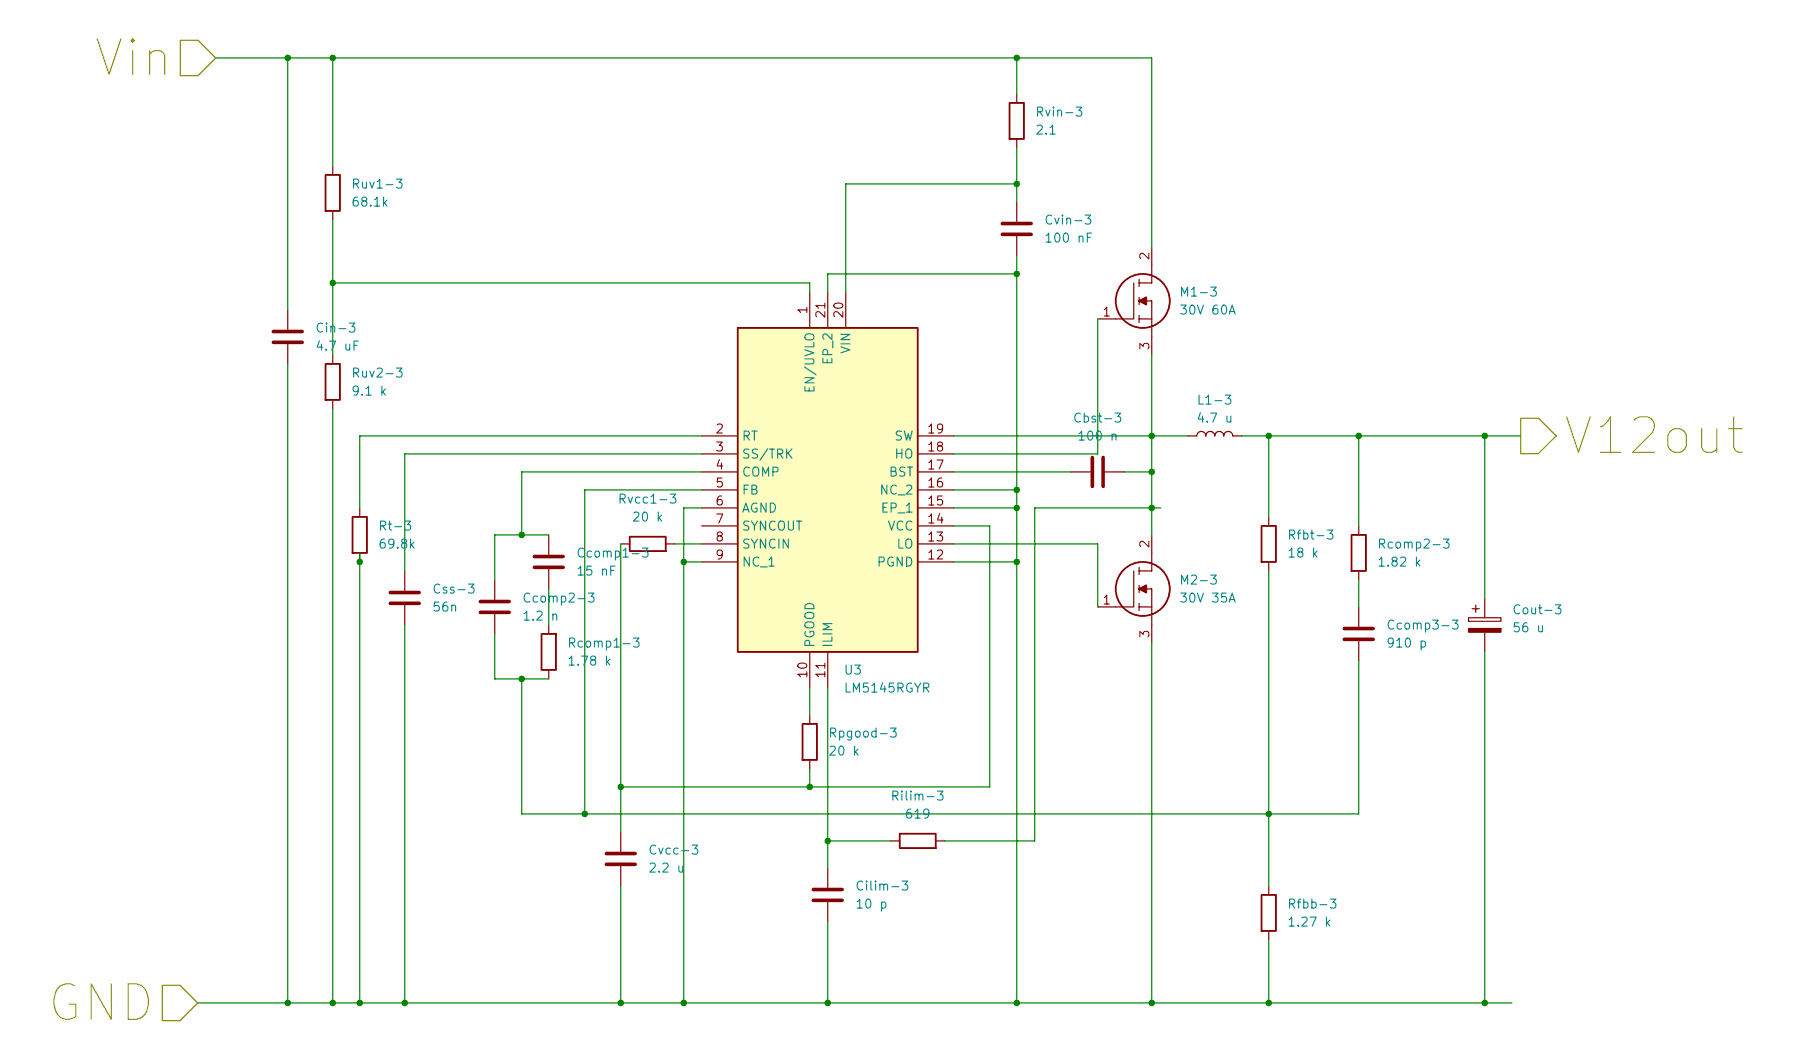
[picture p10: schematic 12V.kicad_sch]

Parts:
Cbst-3: 100 n; C_0603_1608Metric; Manufacturer_Part_Number C0603C104J1RACAUTO
Ccomp1-3: 15 nF; C_0402_1005Metric; Manufacturer_Part_Number GRM155R71C153KA01D
Ccomp2-3: 1.2 n; C_0402_1005Metric; Manufacturer_Part_Number GRM155R71H122KA01D
Ccomp3-3: 910 p; C_0402_1005Metric; Manufacturer_Part_Number GRM1555C1H911JA01D
Cilim-3: 10 p; C_0603_1608Metric; Manufacturer_Part_Number GRM1885C2A100JA01D
Cin-3: 4.7 uF; C_1210_3225Metric; Manufacturer_Part_Number GRM32ER71H475KA88L
Cout-3: 56 u; C_Radial_D6.3mm_H5.0mm_P2.50mm; Manufacturer_Part_Number APSG250ELL560MF05S
Css-3: 56n; C_0402_1005Metric; Manufacturer_Part_Number GRM155R71C563KA88D
Cvcc-3: 2.2 u; C_0402_1005Metric; Manufacturer_Part_Number C1005X5R1V225K050BC
Cvin-3: 100 nF; C_0603_1608Metric; Manufacturer_Part_Number CGA3E2X7R1H104K080AA
L1-3: 4.7 u; A3mmCoil; Manufacturer_Part_Number D=15mm,N=20,L=20mm,d=2mm
M1-3: 30V 60A; TO545P521X1594X2566-3P; Mouser Part Number 747-IXFX360N10T
M2-3: 30V 35A; TO545P521X1594X2566-3P; Mouser Part Number 747-IXFX360N10T
Rcomp1-3: 1.78 k; R_0402_1005Metric; Manufacturer_Part_Number CRCW04021K78FKED
Rcomp2-3: 1.82 k; R_0402_1005Metric; Manufacturer_Part_Number CRCW04021K82FKED
Rfbb-3: 1.27 k; R_0402_1005Metric; Manufacturer_Part_Number CRCW04021K27FKED
Rfbt-3: 18 k; R_0603_1608Metric; Manufacturer_Part_Number RC0603FR-0718KL
Rilim-3: 619; R_0402_1005Metric; Manufacturer_Part_Number CRCW0402619RFKED
Rpgood-3: 20 k; R_0603_1608Metric; Manufacturer_Part_Number RC0603FR-0720KL
Rt-3: 69.8k; R_0402_1005Metric; Manufacturer_Part_Number CRCW040269K8FKED
Ruv1-3: 68.1k; R_0603_1608Metric; Manufacturer_Part_Number ERA-3VEB6812V
Ruv2-3: 9.1 k; R_0603_1608Metric; Manufacturer_Part_Number RC0603FR-079K1L
Rvcc1-3: 20 k; R_0603_1608Metric; Manufacturer_Part_Number RC0603FR-0720KL
Rvin-3: 2.1; R_0603_1608Metric; Manufacturer_Part_Number CRCW06032R10FKEA
U3: LM5145RGYR; RGY0020B; Manufacturer_Part_Number LM5145RGYR; Mouser Part Number 595-LM5145RGYR

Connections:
/12V/GND: Cilim-3.2, Cin-3.2, Cout-3.2, Css-3.2, Cvcc-3.2, Cvin-3.2, M2-3.3, Rfbb-3.2, Rt-3.2, Ruv2-3.2, U3.6 (AGND), U3.9 (NC_1), U3.12 (PGND), U3.15 (EP_1), U3.16 (NC_2), U3.21 (EP_2); also elsewhere on the board
/12V/V12out: Cout-3.1, L1-3.2, Rcomp2-3.1, Rfbt-3.1; also elsewhere on the board
/12V/Vin: Cin-3.1, M1-3.2, Ruv1-3.1, Rvin-3.1; also elsewhere on the board
unnamed: Ccomp1-3.1, Rcomp1-3.2
unnamed: Ccomp3-3.1, Rcomp2-3.2
unnamed: Cbst-3.1, U3.17 (BST)
unnamed: Ccomp1-3.2, Ccomp2-3.2, U3.4 (COMP)
unnamed: Ruv1-3.2, Ruv2-3.1, U3.1 (EN/UVLO)
unnamed: Ccomp2-3.1, Ccomp3-3.2, Rcomp1-3.1, Rfbb-3.1, Rfbt-3.2, U3.5 (FB)
unnamed: M1-3.1, U3.18 (HO)
unnamed: Cilim-3.1, Rilim-3.1, U3.11 (ILIM)
unnamed: M2-3.1, U3.13 (LO)
unnamed: Rpgood-3.1, U3.10 (PGOOD)
unnamed: Rt-3.1, U3.2 (RT)
unnamed: Css-3.1, U3.3 (SS/TRK)
unnamed: Cbst-3.2, L1-3.1, M1-3.3, M2-3.2, Rilim-3.2, U3.19 (SW)
unnamed: Rvcc1-3.2, U3.8 (SYNCIN)
unnamed: Cvcc-3.1, Rpgood-3.2, Rvcc1-3.1, U3.14 (VCC)
unnamed: Cvin-3.1, Rvin-3.2, U3.20 (VIN)

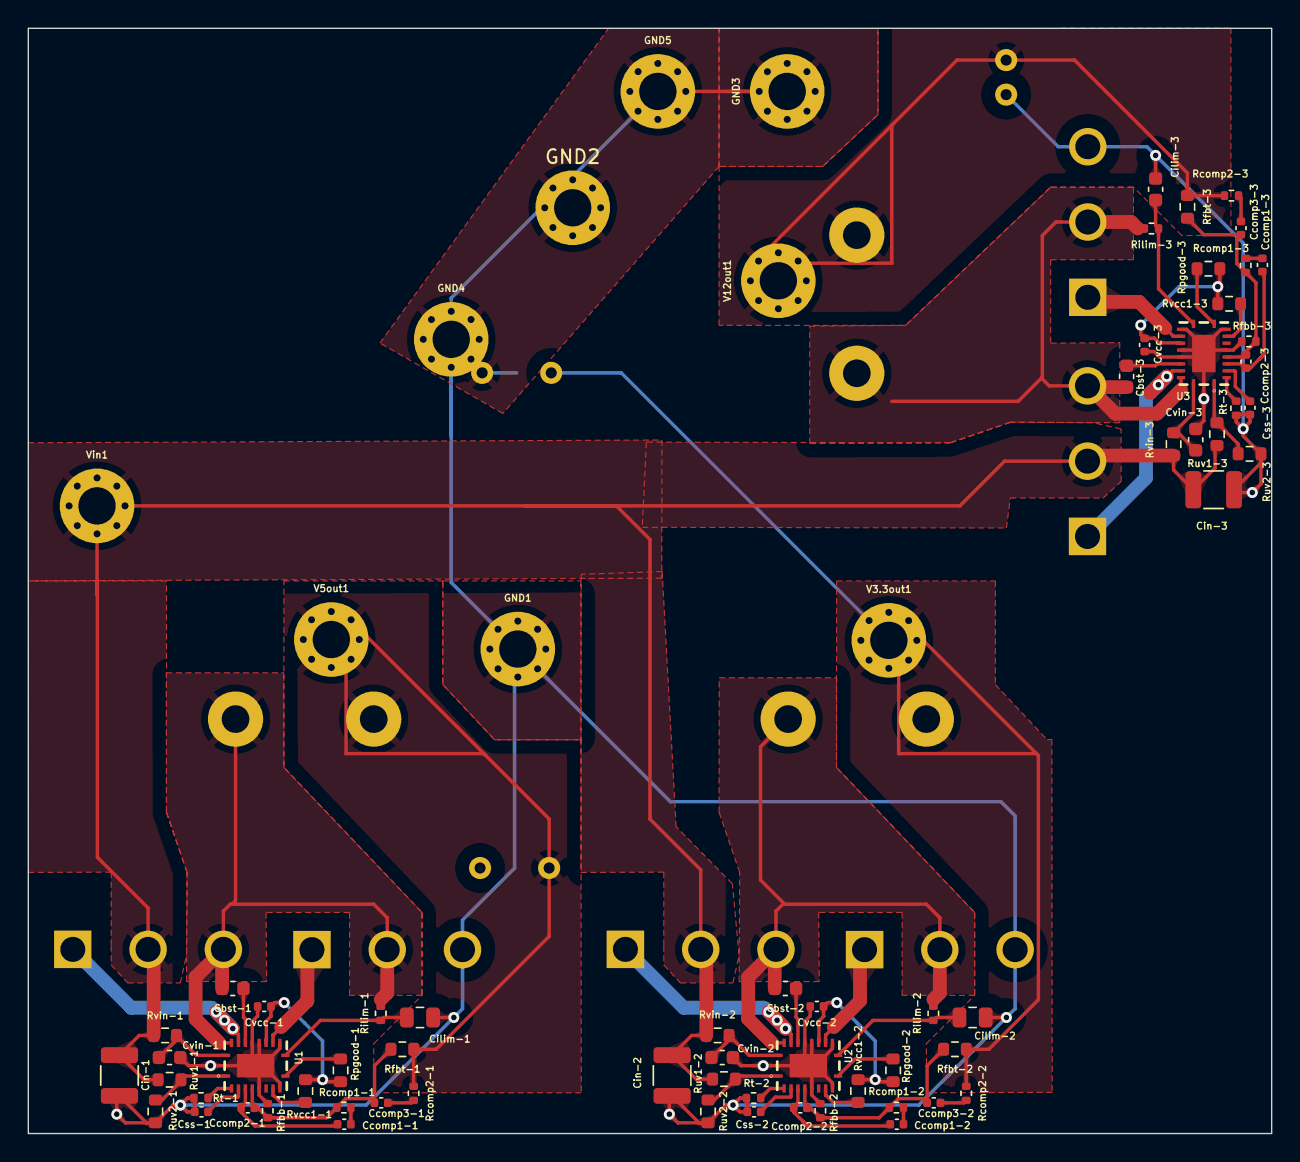
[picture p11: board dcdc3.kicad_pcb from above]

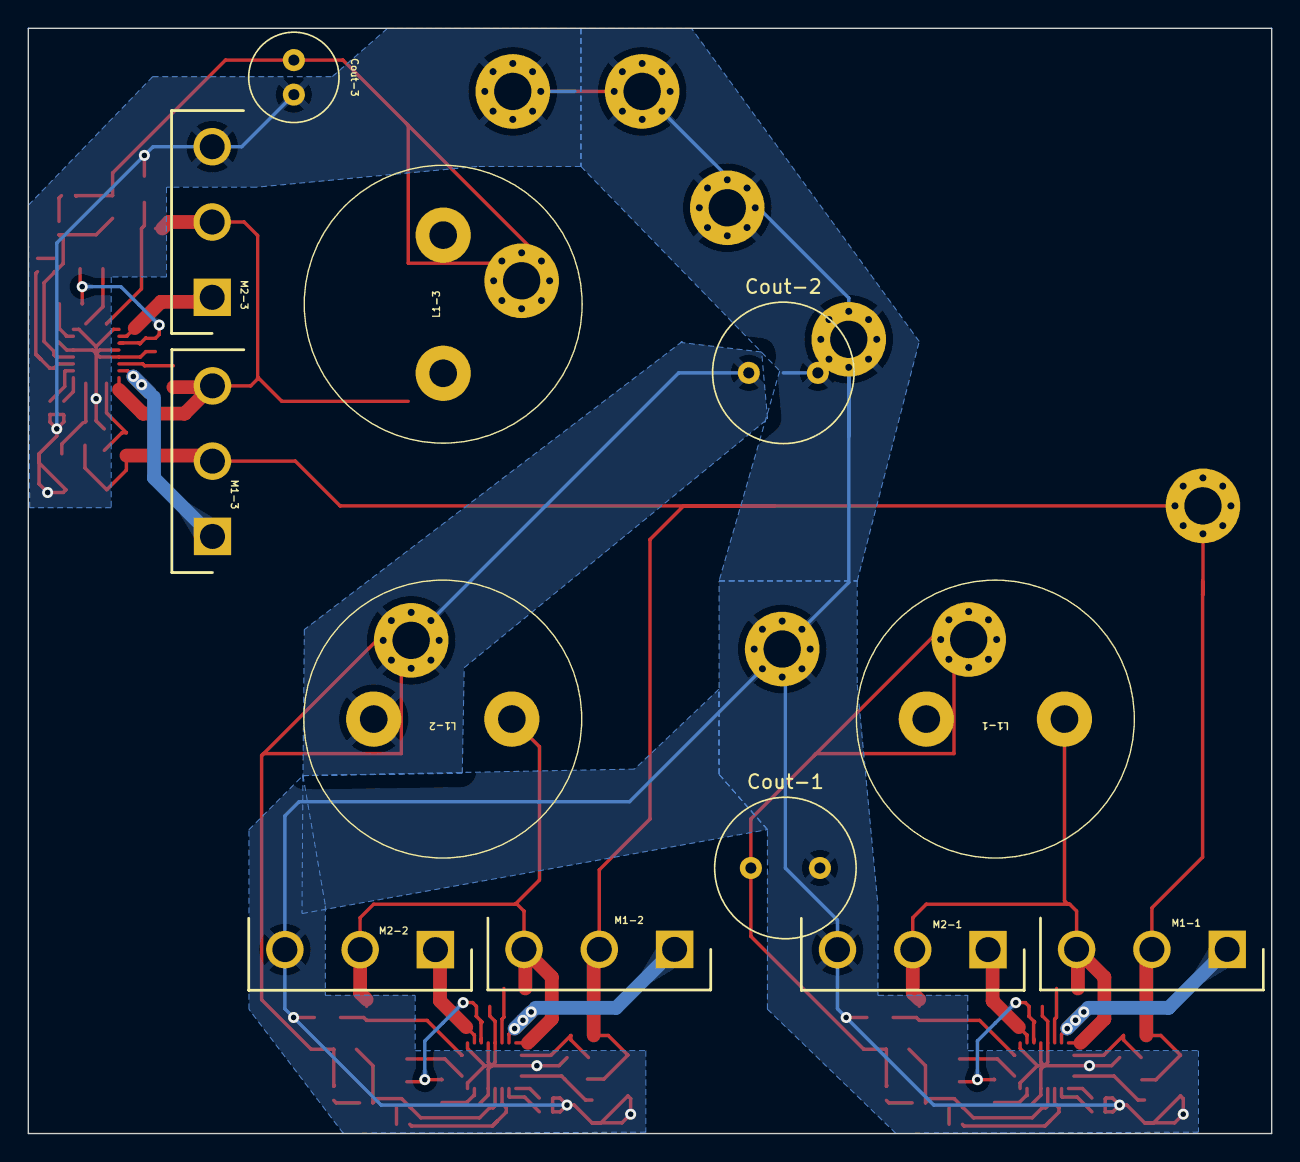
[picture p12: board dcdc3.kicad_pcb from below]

Board: 2 copper layers, 90.0 x 80.0 mm, 84 parts (12 on the bottom side), 53 nets.

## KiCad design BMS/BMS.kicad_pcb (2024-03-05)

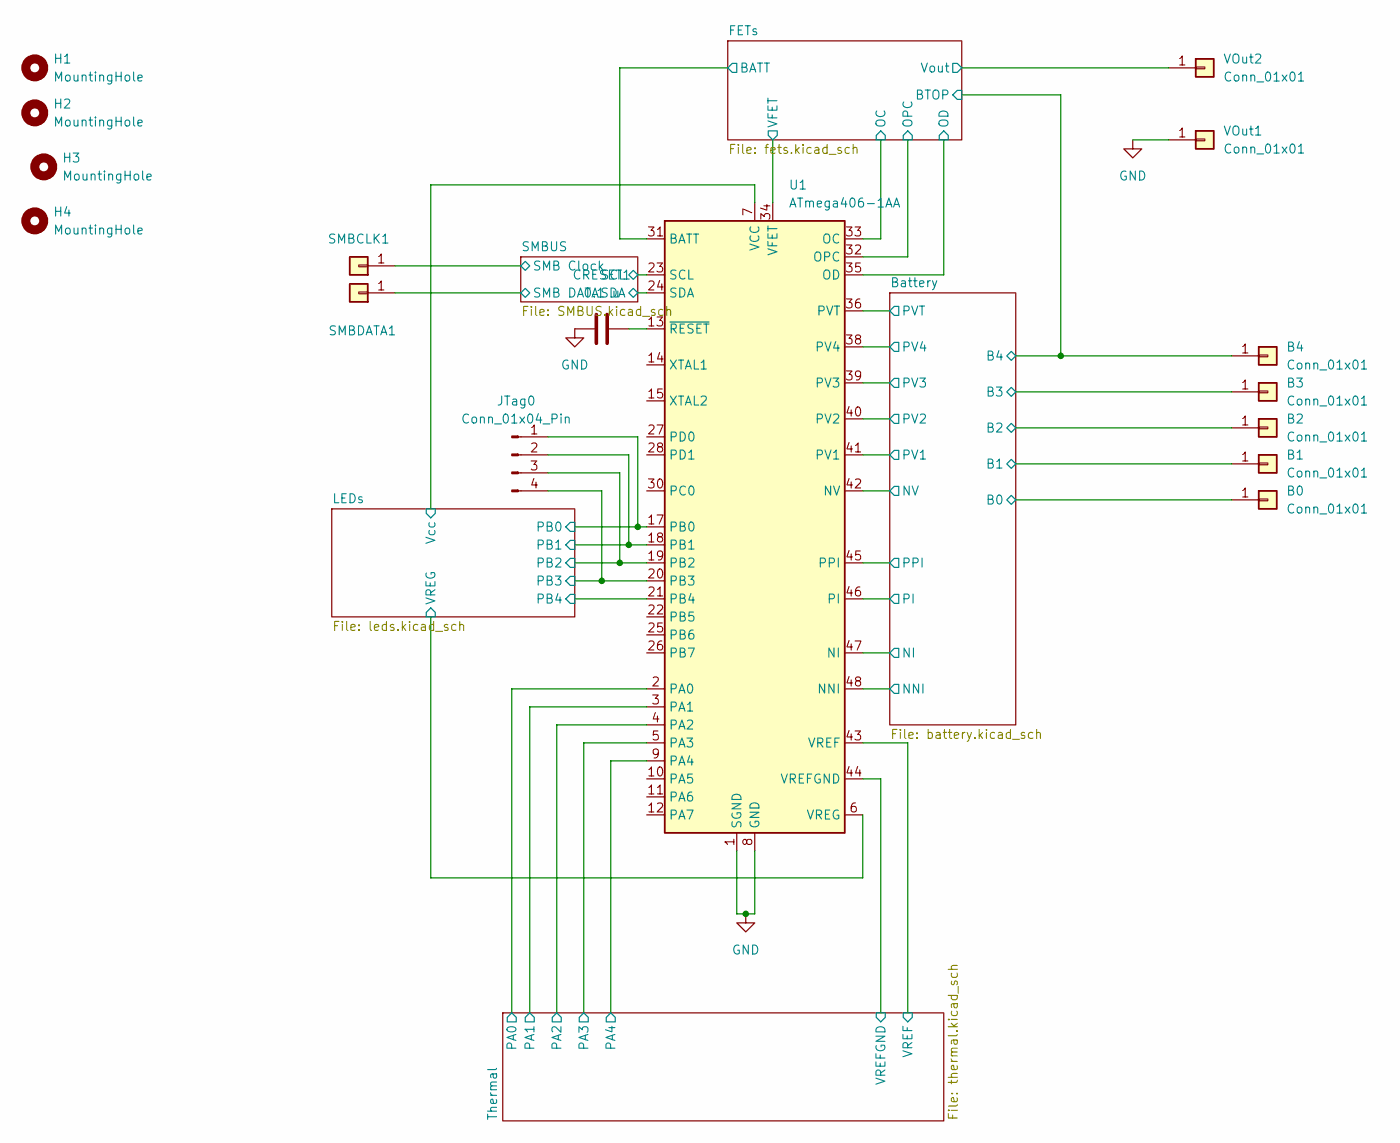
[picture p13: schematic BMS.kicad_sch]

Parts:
B0, B1, B2, B3, B4: Conn_01x01; SolderWire-0.1sqmm_1x01_D0.4mm_OD1mm
CRESET1: 0.1 u; C_0603_1608Metric; Manufacturer_Part_Number KAM15AR71H104KT
H1, H2, H3, H4: MountingHole; MountingHole_2.2mm_M2
JTag0: Conn_01x04_Pin; PinHeader_1x04_P2.00mm_Horizontal
SMBCLK1: Conn_01x01; SolderWire-0.1sqmm_1x01_D0.4mm_OD1mm
SMBDATA1: Conn_01x01; SolderWire-0.1sqmm_1x01_D0.4mm_OD1mm
U1: ATmega406-1AA; LQFP-48_7x7mm_P0.5mm; Manufacturer_Part_Number ATmega406-1AA
VOut1, VOut2: Conn_01x01; SolderWire-0.1sqmm_1x01_D0.4mm_OD1mm

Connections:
/Battery/B0: B0.1; also elsewhere on the board
/Battery/B1: B1.1; also elsewhere on the board
/Battery/B2: B2.1; also elsewhere on the board
/Battery/B3: B3.1; also elsewhere on the board
/Battery/B4: B4.1; also elsewhere on the board
/Battery/NI: U1.47 (NI); also elsewhere on the board
/Battery/NNI: U1.48 (NNI); also elsewhere on the board
/Battery/NV: U1.42 (NV); also elsewhere on the board
/Battery/PI: U1.46 (PI); also elsewhere on the board
/Battery/PPI: U1.45 (PPI); also elsewhere on the board
/Battery/PV1: U1.41 (PV1); also elsewhere on the board
/Battery/PV2: U1.40 (PV2); also elsewhere on the board
/Battery/PV3: U1.39 (PV3); also elsewhere on the board
/Battery/PV4: U1.38 (PV4); also elsewhere on the board
/Battery/PVT: U1.36 (PVT); also elsewhere on the board
/FETs/BATT: U1.31 (BATT); also elsewhere on the board
/FETs/OC: U1.33 (OC); also elsewhere on the board
/FETs/OD: U1.35 (OD); also elsewhere on the board
/FETs/OPC: U1.32 (OPC); also elsewhere on the board
/FETs/VFET: U1.34 (VFET); also elsewhere on the board
/FETs/Vout: VOut2.1; also elsewhere on the board
/LEDs/PB0: JTag0.1, U1.17 (PB0); also elsewhere on the board
/LEDs/PB1: JTag0.2, U1.18 (PB1); also elsewhere on the board
/LEDs/PB2: JTag0.3, U1.19 (PB2); also elsewhere on the board
/LEDs/PB3: JTag0.4, U1.20 (PB3); also elsewhere on the board
/LEDs/PB4: U1.21 (PB4); also elsewhere on the board
/LEDs/VREG: U1.6 (VREG), U1.7 (VCC); also elsewhere on the board
/SMBUS/SCL: SMBCLK1.1, U1.23 (SCL); also elsewhere on the board
/SMBUS/SDA: SMBDATA1.1, U1.24 (SDA); also elsewhere on the board
/Thermal/PA0: U1.2 (PA0); also elsewhere on the board
/Thermal/PA1: U1.3 (PA1); also elsewhere on the board
/Thermal/PA2: U1.4 (PA2); also elsewhere on the board
/Thermal/PA3: U1.5 (PA3); also elsewhere on the board
/Thermal/PA4: U1.9 (PA4); also elsewhere on the board
/Thermal/VREF: U1.43 (VREF); also elsewhere on the board
/Thermal/VREFGND: U1.44 (VREFGND); also elsewhere on the board
GND: CRESET1.1, U1.1 (SGND), U1.8 (GND), U1.16 (GND), U1.29 (GND), U1.37 (GND), VOut1.1; also elsewhere on the board
unnamed: CRESET1.2, U1.13 (~RESET)

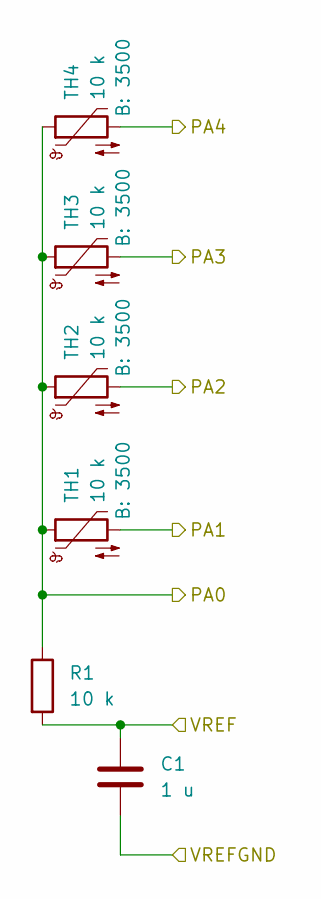
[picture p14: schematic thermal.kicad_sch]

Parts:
C1: 1 u; C_0805_2012Metric; Manufacturer_Part_Number KGM21AR71H105JU
R1: 10 k; R_0402_1005Metric; Manufacturer_Part_Number CRCW040210K0FKEDC
TH1, TH2, TH3, TH4: 10 k; R_Axial_DIN0204_L3.6mm_D1.6mm_P1.90mm_Vertical; Manufacturer_Part_Number 214650-1633

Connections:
/Thermal/PA0: R1.1, TH1.1, TH2.1, TH3.1, TH4.1; also elsewhere on the board
/Thermal/PA1: TH1.2; also elsewhere on the board
/Thermal/PA2: TH2.2; also elsewhere on the board
/Thermal/PA3: TH3.2; also elsewhere on the board
/Thermal/PA4: TH4.2; also elsewhere on the board
/Thermal/VREF: C1.1, R1.2; also elsewhere on the board
/Thermal/VREFGND: C1.2; also elsewhere on the board

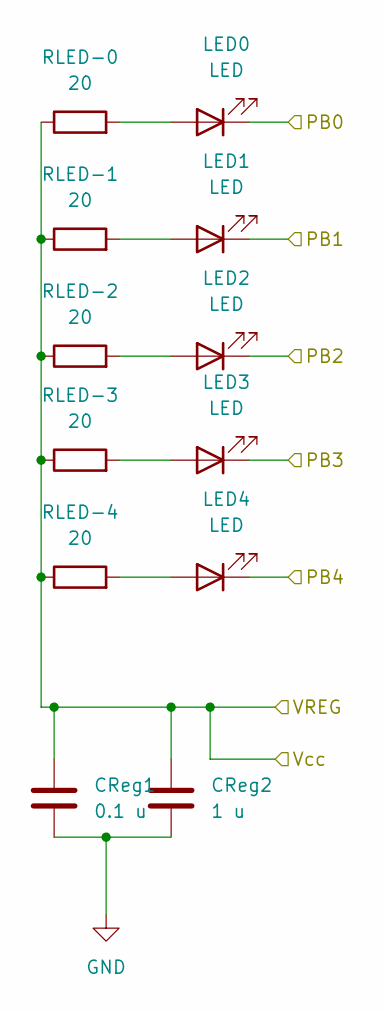
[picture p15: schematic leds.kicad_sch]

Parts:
CReg1: 0.1 u; C_0603_1608Metric; Manufacturer_Part_Number KAM15AR71H104KT
CReg2: 1 u; C_0805_2012Metric; Manufacturer_Part_Number KGM21AR71H105JU
LED0, LED1, LED2, LED3, LED4: LED; D_0603_1608Metric; Manufacturer_Part_Number ASCKCA00-BU4V4020502
RLED-0, RLED-1, RLED-2, RLED-3, RLED-4: 20; R_0402_1005Metric; Manufacturer_Part_Number ESR01MZPF20R0

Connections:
/LEDs/PB0: LED0.1 (K); also elsewhere on the board
/LEDs/PB1: LED1.1 (K); also elsewhere on the board
/LEDs/PB2: LED2.1 (K); also elsewhere on the board
/LEDs/PB3: LED3.1 (K); also elsewhere on the board
/LEDs/PB4: LED4.1 (K); also elsewhere on the board
/LEDs/VREG: CReg1.1, CReg2.1, RLED-0.1, RLED-1.1, RLED-2.1, RLED-3.1, RLED-4.1; also elsewhere on the board
GND: CReg1.2, CReg2.2; also elsewhere on the board
unnamed: LED0.2 (A), RLED-0.2
unnamed: LED1.2 (A), RLED-1.2
unnamed: LED2.2 (A), RLED-2.2
unnamed: LED3.2 (A), RLED-3.2
unnamed: LED4.2 (A), RLED-4.2

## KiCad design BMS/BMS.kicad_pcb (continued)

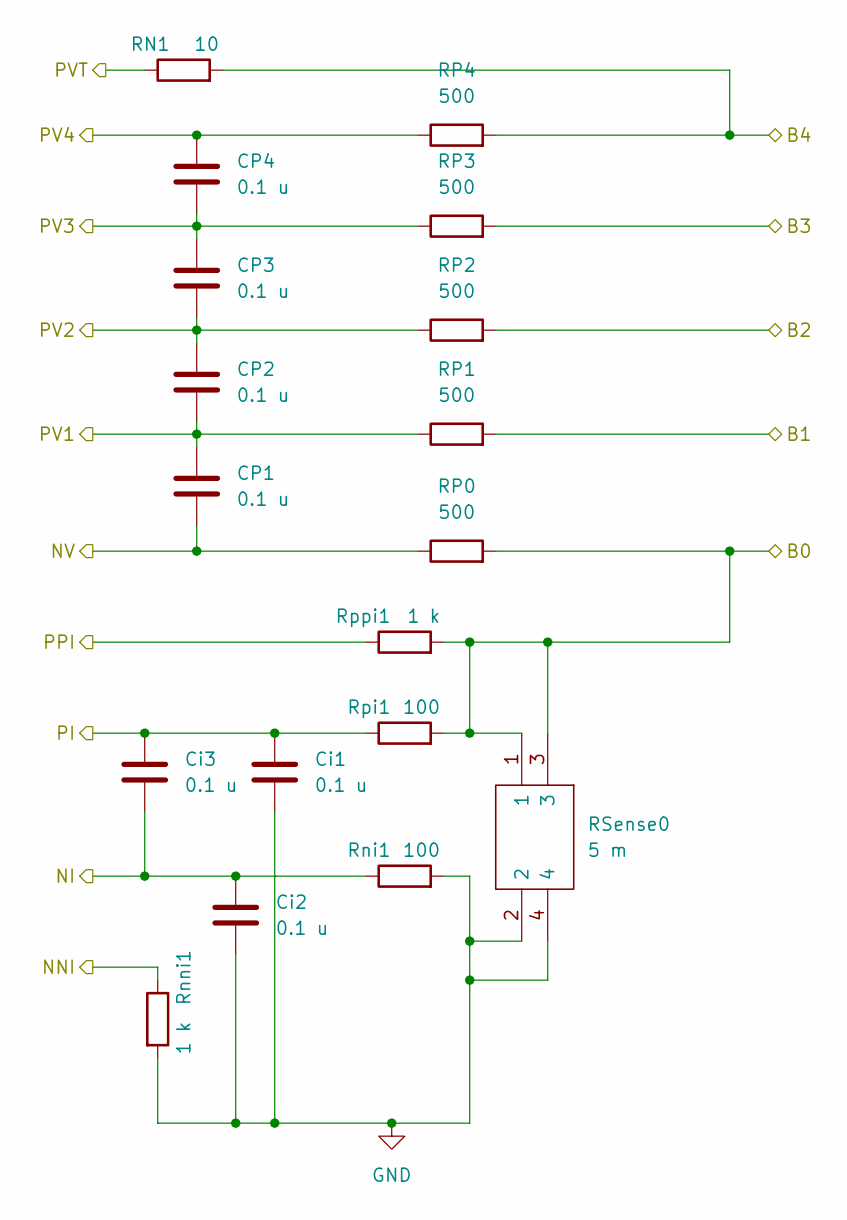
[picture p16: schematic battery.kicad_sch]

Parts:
CP1, CP2, CP3, CP4: 0.1 u; C_0603_1608Metric; Manufacturer_Part_Number KAM15AR71H104KT
Ci1, Ci2, Ci3: 0.1 u; C_0603_1608Metric; Manufacturer_Part_Number KAM15AR71H104KT
RN1: 10; R_0402_1005Metric; Manufacturer_Part_Number ERJ-U0XF10R0Y
RP0, RP1, RP2, RP3, RP4: 500; R_1206_3216Metric; Manufacturer_Part_Number MCA12060D5000BP500
RSense0: 5 m; Y14880R00500B9R; Mouser Part Number 71-CSM36370R0050BST
Rni1: 100; R_0603_1608Metric; Manufacturer_Part_Number APC0603T100RZ
Rnni1: 1 k; R_0402_1005Metric; Manufacturer_Part_Number 71-PTN0402Y5000BST1
Rpi1: 100; R_0603_1608Metric; Manufacturer_Part_Number APC0603T100RZ
Rppi1: 1 k; R_0402_1005Metric; Manufacturer_Part_Number 71-PTN0402Y5000BST1

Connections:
/Battery/B0: RP0.2, RSense0.1, RSense0.3, Rpi1.2, Rppi1.2; also elsewhere on the board
/Battery/B1: RP1.2; also elsewhere on the board
/Battery/B2: RP2.2; also elsewhere on the board
/Battery/B3: RP3.2; also elsewhere on the board
/Battery/B4: RN1.2, RP4.2; also elsewhere on the board
/Battery/NI: Ci2.2, Ci3.1, Rni1.1; also elsewhere on the board
/Battery/NNI: Rnni1.1; also elsewhere on the board
/Battery/NV: CP1.1, RP0.1; also elsewhere on the board
/Battery/PI: Ci1.2, Ci3.2, Rpi1.1; also elsewhere on the board
/Battery/PPI: Rppi1.1; also elsewhere on the board
/Battery/PV1: CP1.2, CP2.1, RP1.1; also elsewhere on the board
/Battery/PV2: CP2.2, CP3.1, RP2.1; also elsewhere on the board
/Battery/PV3: CP3.2, CP4.1, RP3.1; also elsewhere on the board
/Battery/PV4: CP4.2, RP4.1; also elsewhere on the board
/Battery/PVT: RN1.1; also elsewhere on the board
GND: Ci1.1, Ci2.1, RSense0.2, RSense0.4, Rni1.2, Rnni1.2; also elsewhere on the board

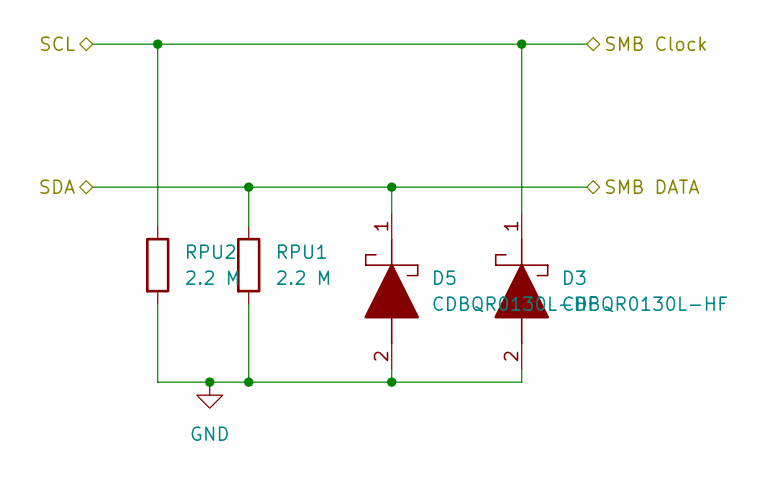
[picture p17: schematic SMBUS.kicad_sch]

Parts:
D3, D5: CDBQR0130L-HF; D_0402_1005Metric; Manufacturer_Part_Number CDBQR0130L-HF
RPU1, RPU2: 2.2 M; R_2010_5025Metric; Manufacturer_Part_Number RCV20102M20JNEF

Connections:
/SMBUS/SCL: D3.1, RPU2.1; also elsewhere on the board
/SMBUS/SDA: D5.1, RPU1.1; also elsewhere on the board
GND: D3.2, D5.2, RPU1.2, RPU2.2; also elsewhere on the board

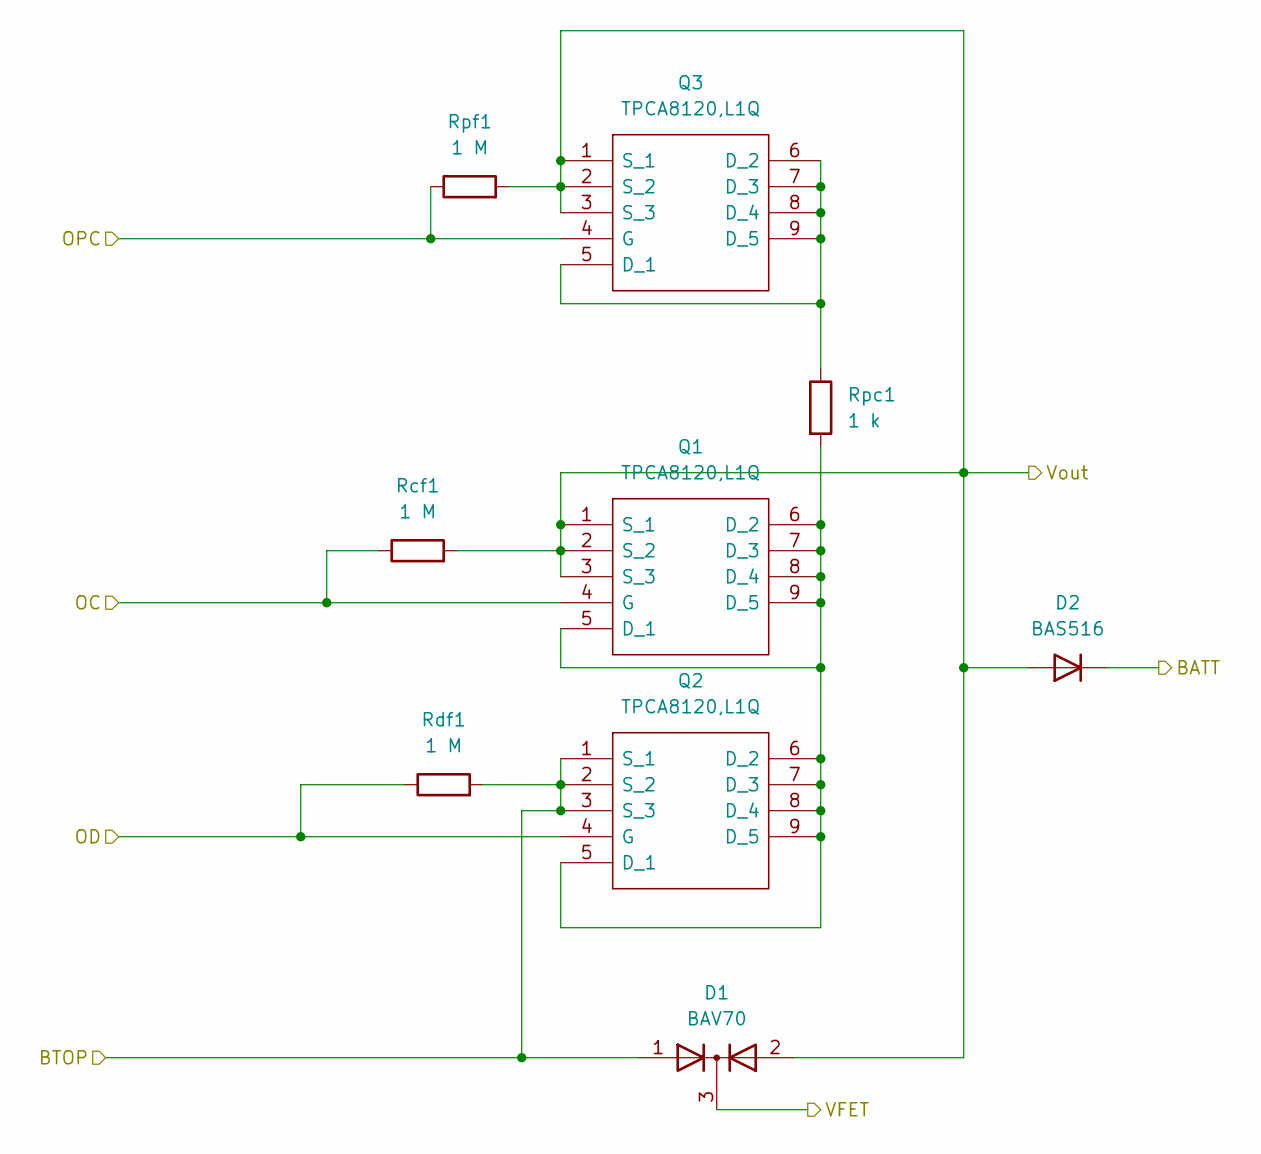
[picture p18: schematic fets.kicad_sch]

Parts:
D1: BAV70; SOT-23; Manufacturer_Part_Number BAV70,215
D2: BAS516; D_SOD-523; Manufacturer_Part_Number BAS516,135
Q1, Q2, Q3: TPCA8120,L1Q; TPH4R003NLL1Q; Mouser Part Number 757-TPCA8120L1Q
Rcf1: 1 M; R_0402_1005Metric; Manufacturer_Part_Number 560112110033
Rdf1: 1 M; R_0402_1005Metric; Manufacturer_Part_Number 560112110033
Rpc1: 1 k; R_2512_6332Metric; Manufacturer_Part_Number 71-PTN0402Y5000BST1
Rpf1: 1 M; R_0402_1005Metric; Manufacturer_Part_Number 560112110033

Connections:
/Battery/B4: D1.1 (A), Q2.1 (S_1), Q2.2 (S_2), Q2.3 (S_3), Rdf1.2; also elsewhere on the board
/FETs/BATT: D2.1 (K); also elsewhere on the board
/FETs/OC: Q1.4 (G), Rcf1.1; also elsewhere on the board
/FETs/OD: Q2.4 (G), Rdf1.1; also elsewhere on the board
/FETs/OPC: Q3.4 (G), Rpf1.1; also elsewhere on the board
/FETs/VFET: D1.3 (K); also elsewhere on the board
/FETs/Vout: D1.2 (A), D2.2 (A), Q1.1 (S_1), Q1.2 (S_2), Q1.3 (S_3), Q3.1 (S_1), Q3.2 (S_2), Q3.3 (S_3), Rcf1.2, Rpf1.2; also elsewhere on the board
unnamed: Q1.5 (D_1), Q1.6 (D_2), Q1.7 (D_3), Q1.8 (D_4), Q1.9 (D_5), Q2.5 (D_1), Q2.6 (D_2), Q2.7 (D_3), Q2.8 (D_4), Q2.9 (D_5), Rpc1.2
unnamed: Q3.5 (D_1), Q3.6 (D_2), Q3.7 (D_3), Q3.8 (D_4), Q3.9 (D_5), Rpc1.1



Board: 2 copper layers, 260.0 x 18.0 mm, 65 parts (2 on the bottom side), 45 nets.

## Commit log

2024-01-28 initial checkin
    [DCDC.csv, DCDC.kicad_pcb, DCDC.kicad_sch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]
2024-01-28 added picoPSU to the part list
    [parts.ods]
2024-01-29 new dc/dc converter design
    [DCDC.csv, DCDC.kicad_pcb, DCDC.kicad_sch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]
2024-01-29 BOM for DC/DC converter
    [WBBOMDesignLM5145RGYR.csv]
2024-02-01 redesign of voltage regulator
    [dcdc3.kicad_pcb, dcdc3.kicad_sch, parts.ods]
2024-02-02 restructured schematics, dumbed down pcb before redesign
    [12V.kicad_sch, 3.3V.kicad_sch, 5V.kicad_sch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]
2024-02-02 pcb part for 5V ready
    [dcdc3.kicad_pcb]
2024-02-02 pcb updated with all parts
    [3.3V.kicad_sch, dcdc3.kicad_pcb, dcdc3.kicad_sch]
2024-02-02 pcb designed for 3 outputs
    [12V.kicad_sch, 3.3V.kicad_sch, 5V.kicad_sch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]
2024-02-07 dcdc simulation, mechanical drawings
    [12V.kicad_sch, 3.3V.kicad_sch, 5V.kicad_sch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]
2024-02-07 one module of the dcdc converter seems ready again...
    [12V.kicad_sch, 3.3V.kicad_sch, 5V.kicad_sch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]
2024-02-10 3 modules of DCDC, hinge
    [12V.kicad_sch, 3.3V.kicad_sch, 5V.kicad_sch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]
2024-02-28 BMS from Atmel datasheet. trying to figure out CNC of the pump and handle
    [BMS.kicad_pcb, BMS.kicad_sch, SMBUS.kicad_sch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]
2024-03-05 DCDC fix unavailable parts, BMS redesign, handle fix, rearrange top half
    [12V.kicad_sch, 3.3V.kicad_sch, 5V.kicad_sch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]
2024-03-16 bottom rearrange
    [parts.ods]
2024-03-18 coil redesign, materials
    [12V.kicad_sch, 3.3V.kicad_sch, 5V.kicad_sch]
